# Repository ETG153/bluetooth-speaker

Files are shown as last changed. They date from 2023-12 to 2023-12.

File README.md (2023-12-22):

# Bluetooth-speaker
Wireless bluetooth speaker with high quality sound.

## Features
- Custom made sound card with an ESP32 and a high quality 24bit 192khz dac, Hi-Fi quality
- Completely wireless: battery charging and BMS included
- Amplifiers and crossover custom made for this product, design is power efficient
- Can support LDAC bluetooth codec for higher music bitrate (up to 990 kbps)

## Documentation
- Schematics can be found in the hardware folder
- Code is self explanatory, thus no documentation is needed
- PlatformIO: https://platformio.org/
- DAC datasheet: https://statics.cirrus.com/pubs/proDatasheet/CS4344-45-48_F2.pdf
- ESP32 datasheet: https://www.espressif.com/sites/default/files/documentation/esp32-wroom-32e_esp32-wroom-32ue_datasheet_en.pdf
- Bluetooth library used: https://github.com/pschatzmann/ESP32-A2DP

- Oamk documentation in its own folder

## Architecture

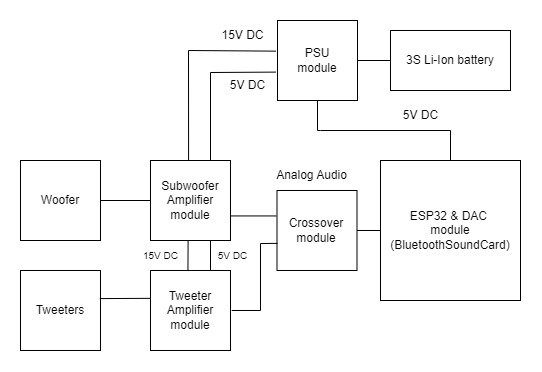
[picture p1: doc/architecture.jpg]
architecture


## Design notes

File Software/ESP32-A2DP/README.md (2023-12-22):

# A Simple Arduino Bluetooth Music Receiver and Sender for the ESP32

The ESP32 is a microcontroller that provides an API for Bluetooth A2DP which can be used to receive sound data e.g. from your Mobile Phone and makes it available via a callback method. The output is a PCM data stream, decoded from SBC format. The documentation can be found [here](https://docs.espressif.com/projects/esp-idf/en/latest/esp32/api-reference/peripherals/i2s.html). 

esp32

I2S is an electrical serial bus interface standard used for connecting digital audio devices together. It is used to communicate PCM audio data between integrated circuits in an electronic device.

So we can just feed the input from Bluetooth to the I2S output: An example for this from Espressif can be found on [Github](https://github.com/espressif/esp-idf/tree/master/examples/bluetooth/bluedroid/classic_bt/a2dp_sink).

Unfortunately this example did not make me happy so I decided to convert it into a simple __Arduino Library__ that is very easy to use from an Arduino Software IDE.

## Supported Bluetooth Protocols

As the name of this libariy implies, it supports the A2DP [Bluetooth protocol](https://en.wikipedia.org/wiki/List_of_Bluetooth_profiles) which only provides audio streaming! 

It also supports Audio/Video Remote Control Profile (AVRCP) together with A2DP.

The Hands-Free Profile (HFP), Headset Profile (HSP) and stand alone AVRCP without A2DP are __not__ supported!

## A2DP Sink (Music Receiver)

This can be used e.g. to build your own Bluetooth Speaker.

### A Simple I2S Example (A2DS Sink) using default Pins
Here is the simplest example which just uses the proper default settings:

```
#include "BluetoothA2DPSink.h"

BluetoothA2DPSink a2dp_sink;

void setup() {
    a2dp_sink.start("MyMusic");
}

void loop() {
}
```
This creates a new Bluetooth device with the name “MyMusic” and the output will be sent to the following default I2S pins which need to be conected to an external DAC:
- bck_io_num = 26
- ws_io_num = 25
- data_out_num = 22

### Defining Pins

You can define your own pins easily by calling the ```set_pin_config``` method in the setup before the ```start```.

```
#include "BluetoothA2DPSink.h"

BluetoothA2DPSink a2dp_sink;

void setup() {
    i2s_pin_config_t my_pin_config = {
        .mck_io_num = I2S_PIN_NO_CHANGE,
        .bck_io_num = 26,
        .ws_io_num = 25,
        .data_out_num = 22,
        .data_in_num = I2S_PIN_NO_CHANGE
    };
    a2dp_sink.set_pin_config(my_pin_config);
    a2dp_sink.start("MyMusic");
}

void loop() {
}
```

### Using your specific i2s_config

In some cases you might want to use your specific i2s_config settings. E.g. to request a different bits_per_sample (e.g. 32) or to use the use_apll or to optimize the dma buffer...

```
#include "BluetoothA2DPSink.h"

BluetoothA2DPSink a2dp_sink;

void setup() {

    static i2s_config_t i2s_config = {
      .mode = (i2s_mode_t) (I2S_MODE_MASTER | I2S_MODE_TX),
      .sample_rate = 44100, // updated automatically by A2DP
      .bits_per_sample = (i2s_bits_per_sample_t)32,
      .channel_format = I2S_CHANNEL_FMT_RIGHT_LEFT,
      .communication_format = (i2s_comm_format_t) (I2S_COMM_FORMAT_STAND_I2S),
      .intr_alloc_flags = 0, // default interrupt priority
      .dma_buf_count = 8,
      .dma_buf_len = 64,
      .use_apll = true,
      .tx_desc_auto_clear = true // avoiding noise in case of data unavailability
  };
  a2dp_sink.set_i2s_config(i2s_config);
  a2dp_sink.start("MyMusic");
}

void loop() {
}

```

### Output to the Internal DAC
You can also send the output directly to the internal DAC of the ESP32 by providing the corresponding i2s_config:

```
#include "BluetoothA2DPSink.h"

BluetoothA2DPSink a2dp_sink;

void setup() {
    static const i2s_config_t i2s_config = {
        .mode = (i2s_mode_t) (I2S_MODE_MASTER | I2S_MODE_TX | I2S_MODE_DAC_BUILT_IN),
        .sample_rate = 44100, // corrected by info from bluetooth
        .bits_per_sample = (i2s_bits_per_sample_t) 16, /* the DAC module will only take the 8bits from MSB */
        .channel_format = I2S_CHANNEL_FMT_RIGHT_LEFT,
        .communication_format = (i2s_comm_format_t)I2S_COMM_FORMAT_STAND_MSB,
        .intr_alloc_flags = 0, // default interrupt priority
        .dma_buf_count = 8,
        .dma_buf_len = 64,
        .use_apll = false
    };

    a2dp_sink.set_i2s_config(i2s_config);
    a2dp_sink.start("MyMusic");

}

void loop() {
}
```

The output goes now to the DAC pins GPIO25 (Channel 1) and GPIO26 (Channel 2).

### Accessing the Sink Data Stream with Callbacks

You can be notified when a packet is received. The API is using PCM data normally formatted as 44.1kHz sampling rate, two-channel 16-bit sample data. 

```
// In the setup function:
a2dp_sink.set_on_data_received(data_received_callback);

// Then somewhere in your sketch:
void data_received_callback() {
  Serial.println("Data packet received");
}
```

Or you can access the packet:

```
// In the setup function:
a2dp_sink.set_stream_reader(read_data_stream);

// Then somewhere in your sketch:
void read_data_stream(const uint8_t *data, uint32_t length)
{
  int16_t *samples = (int16_t*) data;
  uint32_t sample_count = length/2;
  // Do something with the data packet
}
```
In the ```a2dp_sink.set_stream_reader()``` method you can provide an optional parameter that defines if you want the output to I2S to be active or deactive - So you can use this method to e.g. to switch off I2S just by calling ```a2dp_sink.set_stream_reader(read_data_stream, false)```

### Support for Metadata

You can register a method which will be called when the system receives any AVRC metadata. Here is an example
```
void avrc_metadata_callback(uint8_t data1, const uint8_t *data2) {
  Serial.printf("AVRC metadata rsp: attribute id 0x%x, %s\n", data1, data2);
}
a2dp_sink.set_avrc_metadata_callback(avrc_metadata_callback);
a2dp_sink.start("BT");
```
By default you should get the most important information, however you can adjust this by calling the ```set_avrc_metadata_attribute_mask``` method e.g if you just need the title and playing time you can call:
```
set_avrc_metadata_attribute_mask(ESP_AVRC_MD_ATTR_TITLE | ESP_AVRC_MD_ATTR_PLAYING_TIME);
```
before you start the A2DP sink.

### Support for AVRC Commands

I have added the following AVRC commmands, that you can use to 'control' your A2DP Source:

- play();
- pause();
- stop();
- next();
- previous();
- fast_forward();
- rewind();

## A2DP Source (Music Sender)

This can be used to feed e.g. your Bluetooth Speaker with your audio data.

### Sending Data from a A2DS Data Source with a Callback

We can also generate sound and send it e.g. to a Bluetooth Speaker.  

The supported audio codec in ESP32 A2DP is SBC: The API is using PCM data normally formatted as 44.1kHz sampling rate, two-channel 16-bit sample data. 

When you start the BluetoothA2DPSource, you need to pass the Bluetooth name that you want to connect to and a 'call back
function' that generates the sound data:

```
#include "BluetoothA2DPSource.h"

BluetoothA2DPSource a2dp_source;

// callback 
int32_t get_sound_data(Frame *data, int32_t frameCount) {
    // generate your sound data 
    // return the effective length (in frames) of the generated sound  (which usually is identical with the requested len)
    // 1 frame is 2 channels * 2 bytes = 4 bytes
    return frameCount;
}

void setup() {
  a2dp_source.start("MyMusic", get_sound_data);  
}

void loop() {
}

```

In the examples you can find an implentation that generates sound with the help of the sin() function.
You can also inticate multiple alternative Bluetooth names. The system just connects to the first one
which is available:

```
void setup() {
  static std::vector<char*> bt_names = {"MyMusic","RadioPlayer","MusicPlayer"};
  a2dp_source.start(bt_names, get_sound_data); 
} 

```

### Sending Data from a A2DS Data Source with Recorded Data

You can also provide the data directly as simple array of uint8_t:

```
#include "BluetoothA2DPSource.h"

extern const uint8_t StarWars10_raw[];
extern const unsigned int StarWars10_raw_len;

BluetoothA2DPSource a2dp_source;
SoundData *music = new OneChannelSoundData((int16_t*)StarWars30_raw, StarWars30_raw_len/2);

void setup() {
  a2dp_source.start("RadioPlayer");  
  a2dp_source.write_data(music);
}

void loop() {
}

```

The array can be prepared e.g. in the following way:

  - Open any sound file in Audacity. 
    - Select Tracks -> Resample and select 44100
    - Export -> Export Audio -> Header Raw ; Signed 16 bit PCM
  - Convert to c file e.g. with "xxd -i file_example_WAV_1MG.raw file_example_WAV_1MG.c"
    - add the const qualifier to the generated array definition. E.g const unsigned char file_example_WAV_1MG_raw[] = {

You might want to compile with the Partition Scheme: Huge App!

In the example above we provide the data with one channel. This has the advantage that it uses much less space then 
a 2 channel recording, which you could use in the following way: 

```
SoundData *data = new TwoChannelSoundData((Frame*)StarWars10_raw,StarWars10_raw_len/4);

```

In the constructor you can pass additional parameters:

```
TwoChannelSoundData(Frame *data, int32_t frameCount, bool loop=false);
OneChannelSoundData(int16_t *data, int32_t frameCount, bool loop=false, ChannelInfo channelInfo=Both);
OneChannel8BitSoundData(int8_t *data, int32_t frameCount, bool loop=false, ChannelInfo channelInfo=Both);

```
## Logging

This library uses the ESP32 logger that you can activate in Arduino in - Tools - Core Debug Log.

## Architecture / Dependencies 

The current code is purely dependent on the ESP-IDF (which is also provided by the Arduino ESP32 core). There are no other dependencies and this includes the Arduino API! 

Therefore we support:

- Arduino
- [PlatformIO](https://github.com/pschatzmann/ESP32-A2DP/wiki/PlatformIO)
- [Espressif IDF](https://github.com/pschatzmann/ESP32-A2DP/wiki/Espressif-IDF-as-a-Component)

This restriction limits however the provided examples. 

Before you clone the project, please read the following information which can be found in the [Wiki](https://github.com/pschatzmann/ESP32-A2DP/wiki/Design-Overview).

## Digital Sound Processing

You can use this library stand alone, but it is part of my [audio-tools](https://github.com/pschatzmann/arduino-audio-tools) project. So you can easily enhance this functionality with sound effects, use filters, use alternative audio sinks or audio sources, do FFT etc. Here is a [simple example](https://github.com/pschatzmann/arduino-audio-tools/blob/main/examples/examples-basic-api/basic-a2dp-fft/basic-a2dp-fft.ino) how you can analyse the audio data with FFT.

## Documentation

- The [class documentation can be found here](https://pschatzmann.github.io/ESP32-A2DP/html/group__a2dp.html)
- You can also find further information in the [Wiki](https://github.com/pschatzmann/ESP32-A2DP/wiki)

## Support

I spent a lot of time to provide a comprehensive and complete documentation.
So please read the documentation first and check the issues and discussions before posting any new ones on Github.

Open issues only for bugs and if it is not a bug, use a discussion: Provide enough information about 
- the selected scenario/sketch 
- what exactly you are trying to do
- your hardware
- your software versions
  - ESP32 version from the Board Manager
  - version of the ESP32-A2DP library

to enable others to understand and reproduce your issue.

Finally above all __don't__ send me any e-mails or post questions on my personal website! 

## Show and Tell

Get some inspiration [from projects that were using this library](https://github.com/pschatzmann/ESP32-A2DP/discussions/categories/show-and-tell) and share your projects with the community.

## Installation

For Arduino you can download the library as zip and call include Library -> zip library. Or you can git clone this project into the Arduino libraries folder e.g. with
```
cd  ~/Documents/Arduino/libraries
git clone https://github.com/pschatzmann/ESP32-A2DP.git
```

For other frameworks [see the Wiki](https://github.com/pschatzmann/ESP32-A2DP/wiki)

## Change History

The [Change History can be found in the Wiki](https://github.com/pschatzmann/ESP32-A2DP/wiki/Change-History)

## Sponsor Me

This software is totally free, but you can make me happy by rewarding me with a treat

- [Buy me a coffee](https://www.buymeacoffee.com/philschatzh)
- [Paypal me](https://paypal.me/pschatzmann?country.x=CH&locale.x=en_US)

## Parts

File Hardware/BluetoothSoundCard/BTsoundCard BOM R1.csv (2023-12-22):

Qty | Value | Device | Package | Parts | Description
5 |  | 10-XX | B3F-10XX | S1, S2, S3, S4, S5 | OMRON SWITCH
1 |  | LEDCHIP-LED0603 | CHIP-LED0603 | LED2 | LED
4 |  | MMBT3904 | SOT23 | T1, T2, T3, T4 | NPN Transistor
1 |  | MMFTP3401 | SOT-23 | T5 | MOS FET
1 |  | PINHD-1X2 | 1X02 | JP1 | PIN HEADER
2 |  | R-EU_R0805 | R0805 | FE, FE1 | FERRITE BEAD
1 |  | W237-103 | W237-103 | X1 | WAGO SCREW CLAMP
2 |  | W237-4 | W237-4 | X2, X4 | WAGO SCREW CLAMP
14 | 100n | C-EUC0603 | C0603 | C2, C5, C9, C13, C16, C17, C18, C19, C21, C22, C23, C24, C25, C26 | CAPACITOR, European symbol
7 | 10k | R-EU_R0603 | R0603 | R1, R2, R3, R4, R5, R7, R15 | RESISTOR, European symbol
1 | 10k | R-EU_R0805 | R0805 | R10 | RESISTOR, European symbol
2 | 10n | C-EUC0603 | C0603 | C6, C11 | CAPACITOR, European symbol
3 | 10u | C-EUC0805 | C0805 | C7, C12, C14 | CAPACITOR, European symbol
1 | 1PS76SB10 | 1PS76SB10 | SOD323(F) | D1 | TVS DIODE
7 | 1k | R-EU_R0603 | R0603 | R8, R13, R16, R17, R18, R19, R20 | RESISTOR, European symbol
1 | 1k | R-EU_R1206 | R1206 | R9 | RESISTOR, European symbol
4 | 1u | C-EUC0603 | C0603 | C3, C4, C10, C20 | CAPACITOR, European symbol
1 | 3X2 | 3X2 | 2X3 | U$3
1 | 3k4 | R-EU_R0603 | R0603 | R11 | RESISTOR, European symbol
1 | 4.7u | EEEFK1H4R7RCAP_EEFK_B_PAN-M | CAP_EEFK_B_PAN-M | C1
1 | 5.1V | DIODE-MINIMELF | MINIMELF | D2 | ZENER DIODE
2 | 82r | R-EU_R1206 | R1206 | R12, R14 | RESISTOR, European symbol
1 | AZ1117H-3.3TRE1SOT-223_DIO-L | AZ1117H-3.3TRE1SOT-223_DIO-L | SOT-223_DIO-L | LDO
1 | CS4344-CZZ | CS4344-CZZ | CIR-TSSOP-10 | U2
1 | ESP32-WROOM-32UE_(16MB) | ESP32-WROOM-32UE_(16MB) | IC38_ESP32-WROOM-32UE_(16MB)_E | U1
1 | JST-XH-04-PIN-LONG-PAD | JST-XH-04-PIN-LONG-PAD | JST-XH-04-PACKAGE-LONG-PAD | UART | JST XH Connector 2 Pin
1 | LD3985M30R | LD3985M30R | SOT23-5L_STM | CR1
1 | MCP602SN | MCP602SN | SO08 | IC1 | Single Op Amp 2.7V to 6.0V Single Supply CMOS
4 | MOUNT-PAD-ROUND3.2 | MOUNT-PAD-ROUND3.2 | 3,2-PAD | H1, H2, H3, H4 | MOUNTING PAD, round
1 | TPPAD1-13 | TPPAD1-13 | P1-13 | TP6 | Test pad
1 | TPSC336K010R0375 | TPSC336K010R0375 | TPSC336K010R0375_AVX | C8 | 33uF low ESR tantalum capacitor

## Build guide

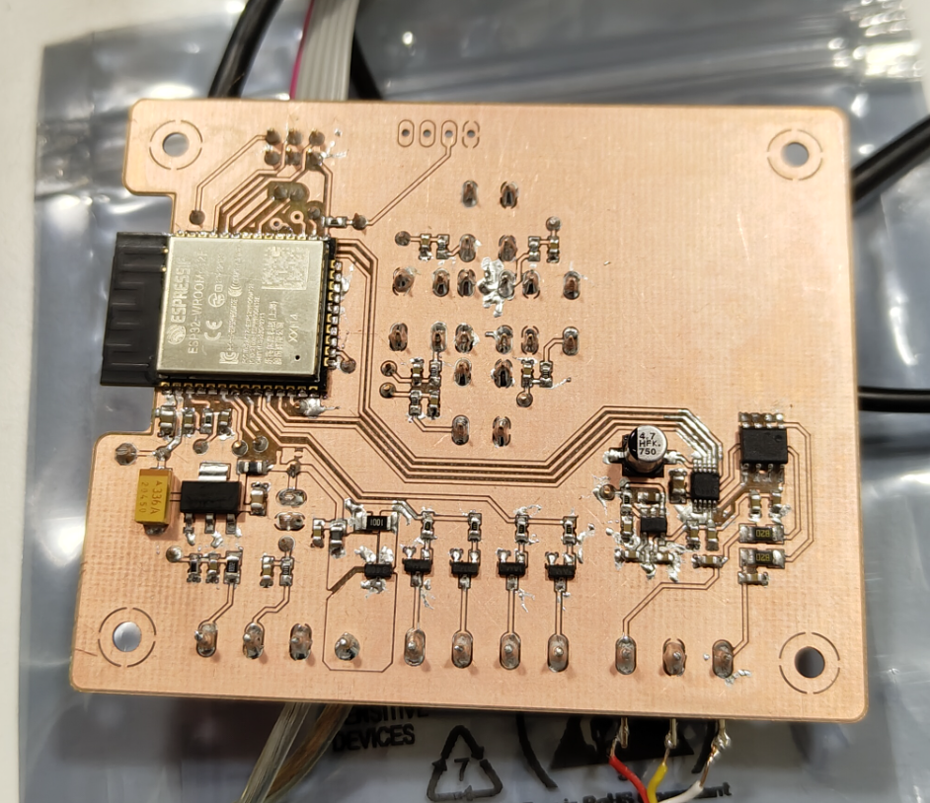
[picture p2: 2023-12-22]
Hardware/BluetoothSoundCard/Proto/assembled-prototype.png

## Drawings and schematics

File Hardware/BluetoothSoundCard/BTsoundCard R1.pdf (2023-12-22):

GND | GND ¹⁰k | 10k 1k GND
10u Power | DAC

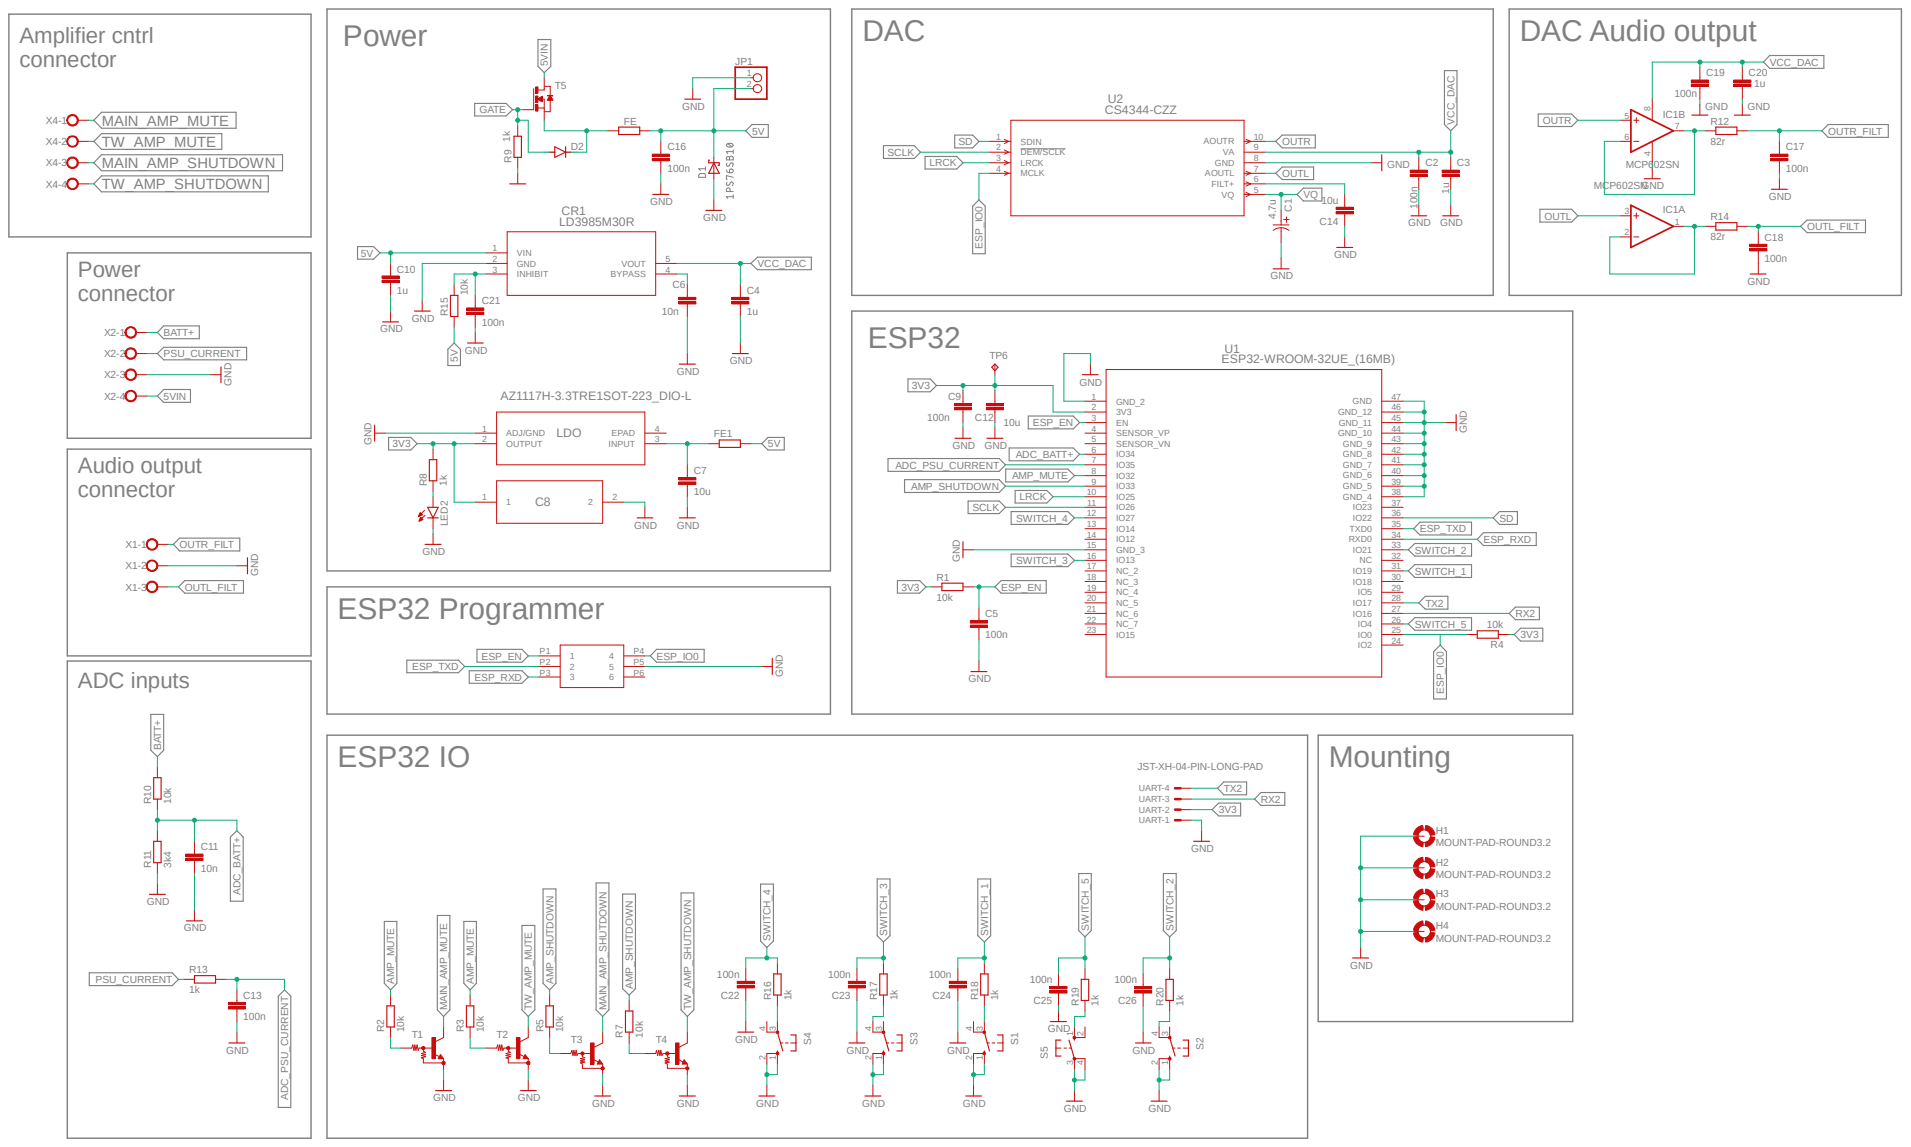
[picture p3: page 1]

IO14 13 IO12 14 | ESP_TXD

NC_7 22 | | 10k
IO15 23 | 3V3

ESP_TXD P2 P3 ESP_RXD | P5 P6

ESP_EN | 1 4 2 5 3 6

JST-XH-04-PIN-LONG-PAD

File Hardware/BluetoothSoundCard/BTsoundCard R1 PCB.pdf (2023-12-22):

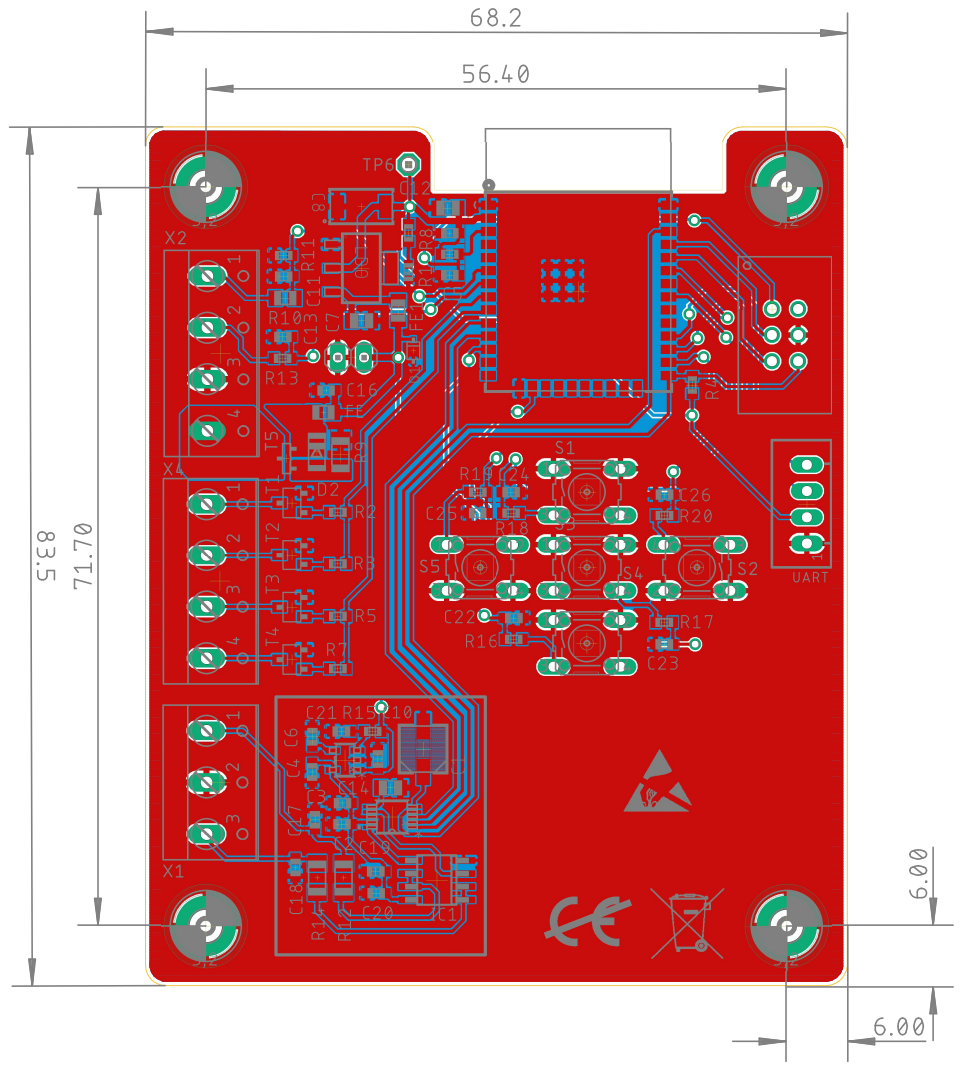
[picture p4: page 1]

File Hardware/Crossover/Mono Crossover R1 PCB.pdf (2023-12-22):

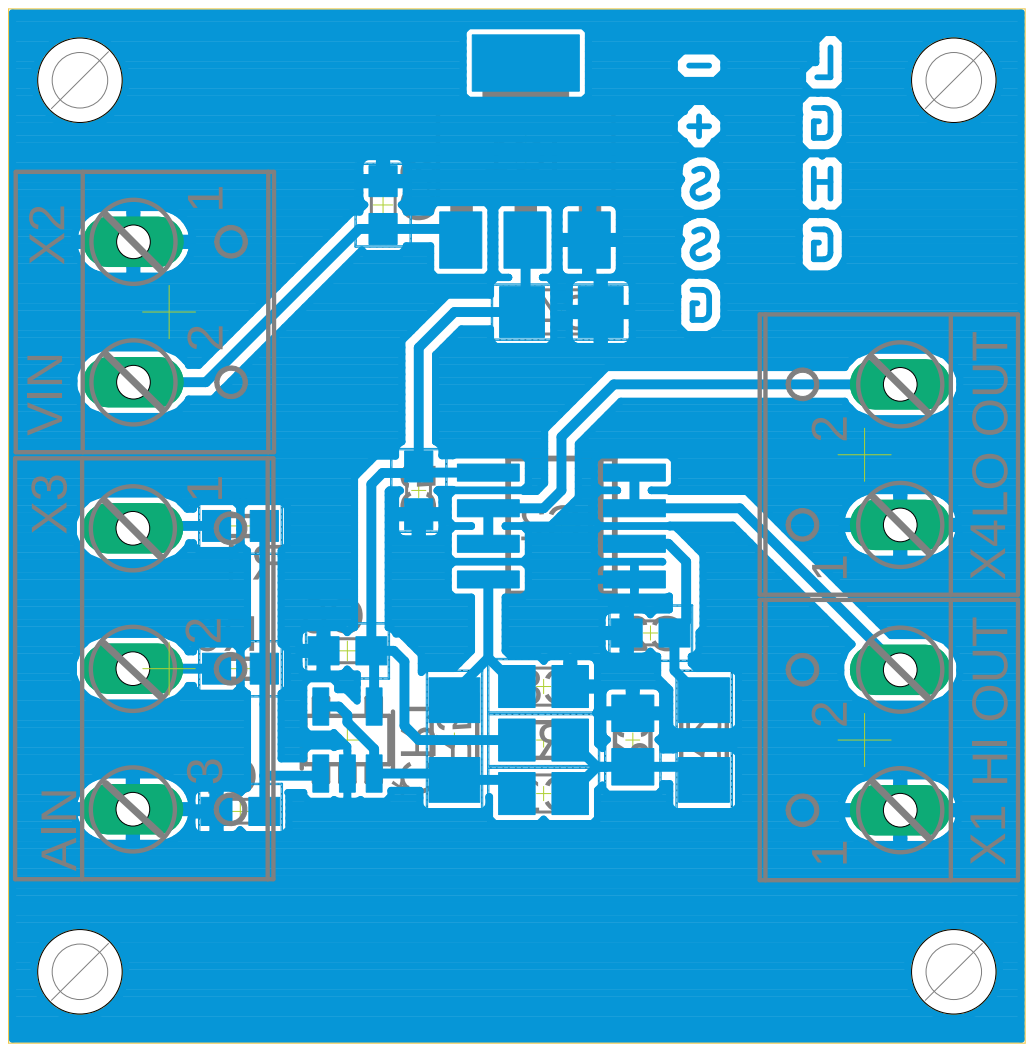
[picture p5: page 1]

CR1 1 C 2 C 8 C C5 C3 4 C 2 CI 1 CI R3 R2R51 R 4 R 6 R 6 C 7 C * 1 2 1 2 1 2 1 2 3 X2 X1 X X4 3 VIN HI OUT LO OUT AIN

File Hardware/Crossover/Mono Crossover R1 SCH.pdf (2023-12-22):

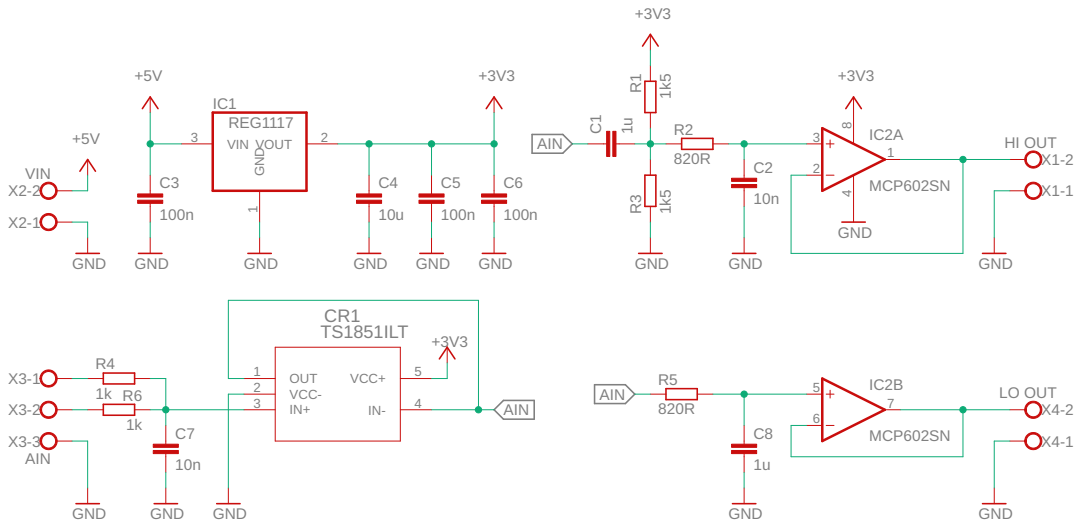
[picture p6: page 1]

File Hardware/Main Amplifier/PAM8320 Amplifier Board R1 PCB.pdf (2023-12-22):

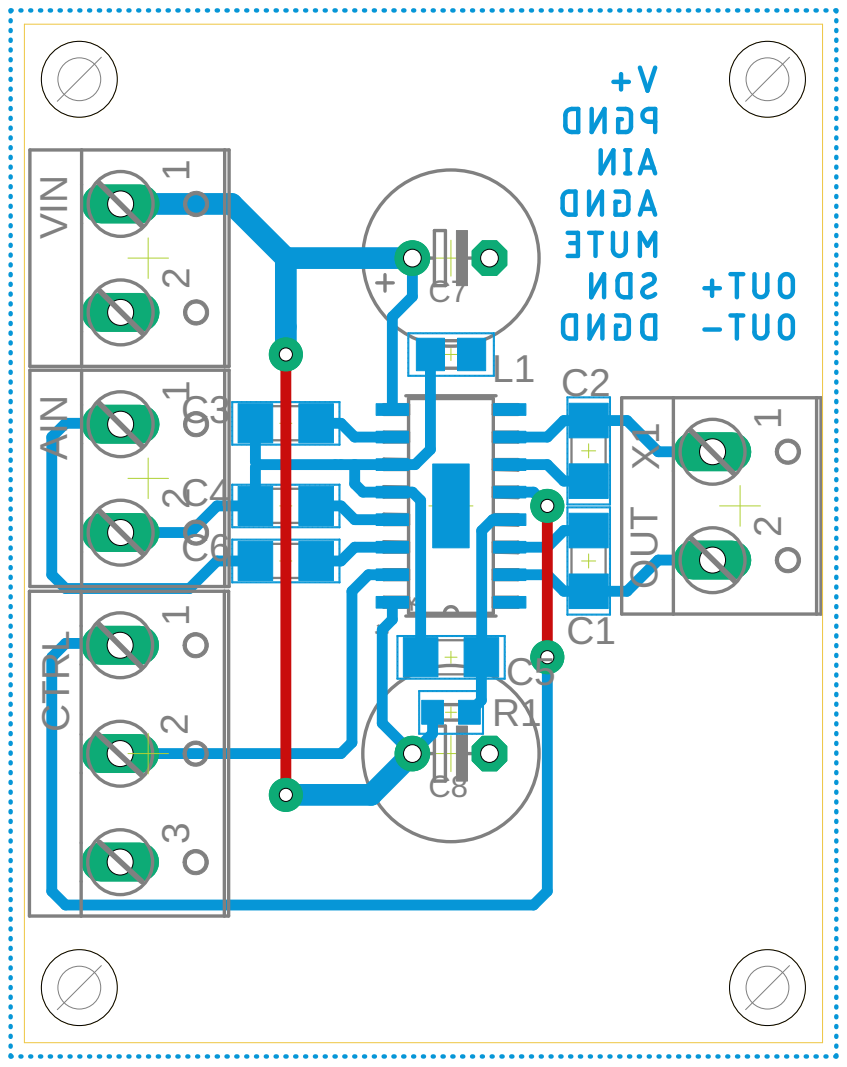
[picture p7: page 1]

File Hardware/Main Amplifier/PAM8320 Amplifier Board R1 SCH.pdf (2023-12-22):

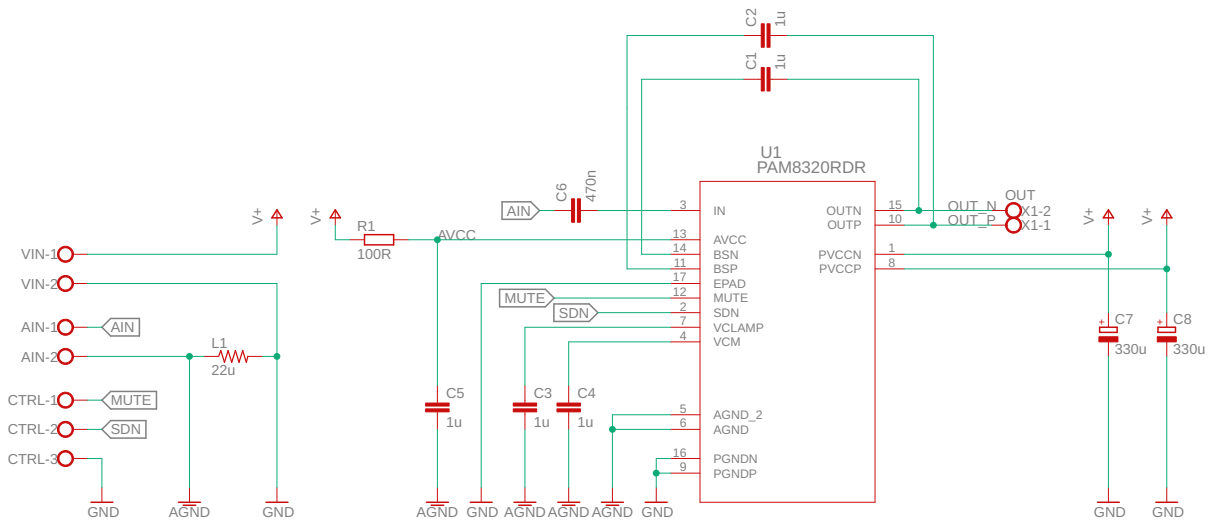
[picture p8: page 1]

13
14

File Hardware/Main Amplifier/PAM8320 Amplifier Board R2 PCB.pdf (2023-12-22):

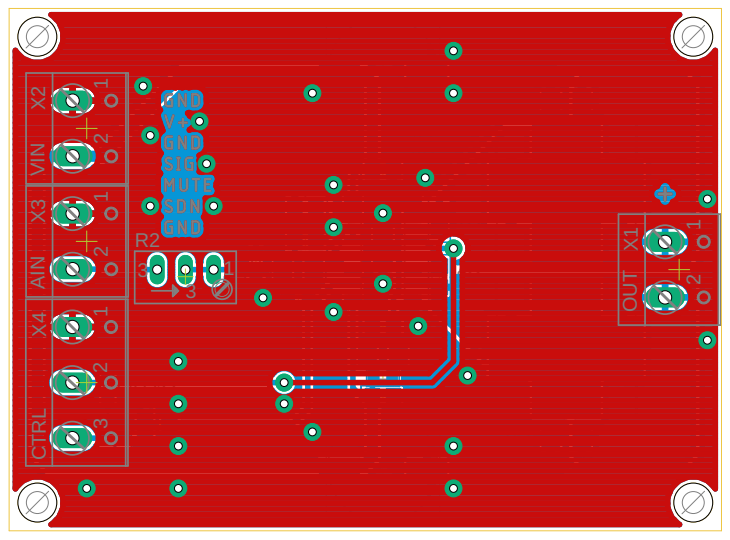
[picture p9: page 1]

2 C1 C 21 C 31 C 11 C 5 C 1 R 8 C9 C 6 C 7 C 01 C 3 C4 C 6 R1 Q 7 R 4 R 5 R * * 1 2 1 2 1 23 1 2 3 3 1 X3 X4 X2 X1R2 AIN CTRL VIN OUT

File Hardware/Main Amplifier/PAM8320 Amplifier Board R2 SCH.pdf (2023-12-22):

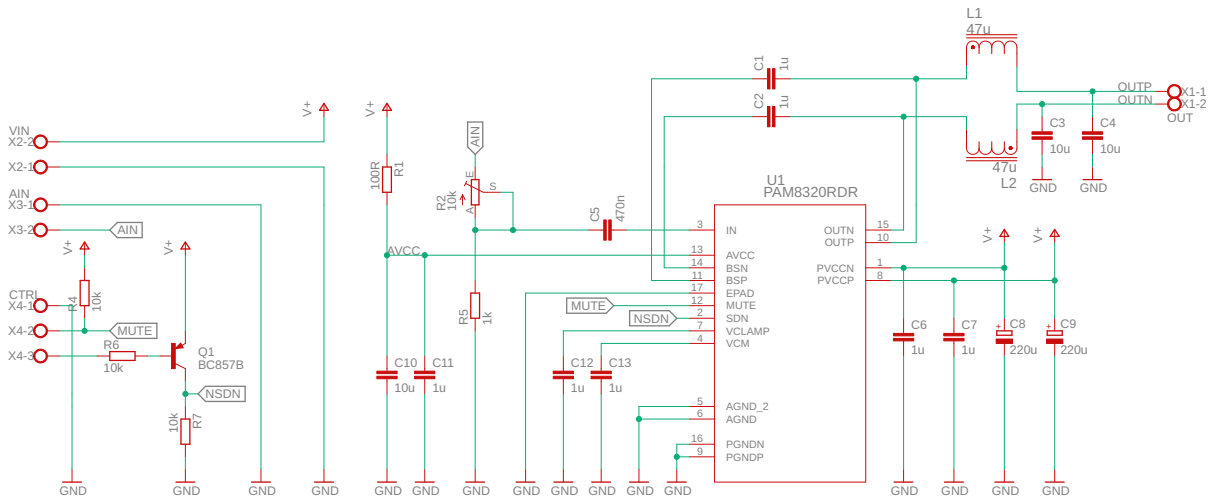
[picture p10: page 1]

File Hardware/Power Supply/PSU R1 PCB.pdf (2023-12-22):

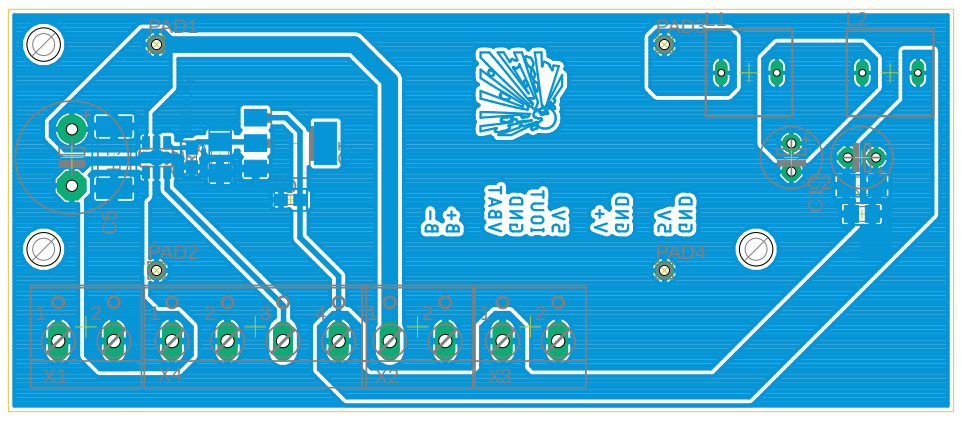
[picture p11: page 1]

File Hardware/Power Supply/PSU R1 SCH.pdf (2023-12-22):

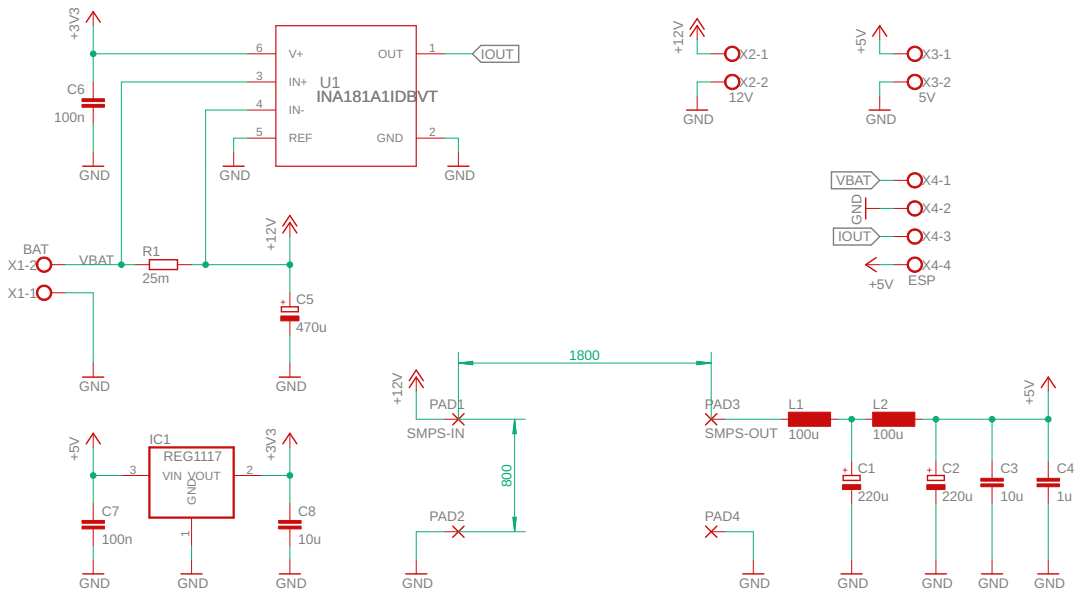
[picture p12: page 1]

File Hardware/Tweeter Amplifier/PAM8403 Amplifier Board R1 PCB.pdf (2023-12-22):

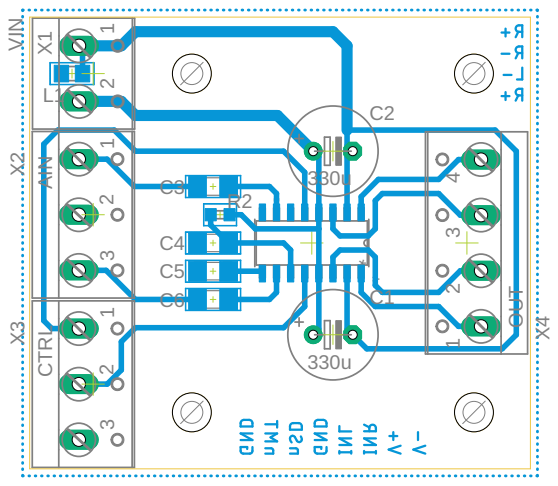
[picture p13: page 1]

* * 1 2 1 2 3 1 2 3 1 2 3 4 C5 C4 C6 X3 L1 R2 X1 C1 C2 X2 C3 X4 CTRL VIN 330u A330u IN OUT

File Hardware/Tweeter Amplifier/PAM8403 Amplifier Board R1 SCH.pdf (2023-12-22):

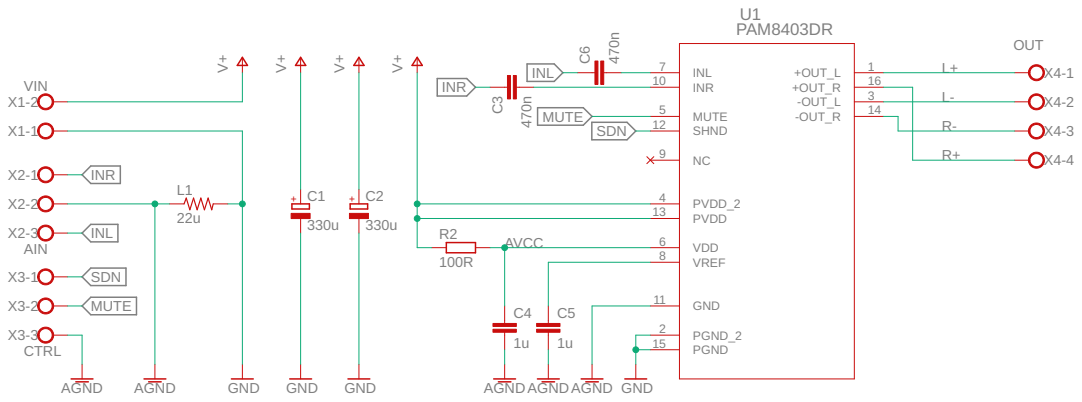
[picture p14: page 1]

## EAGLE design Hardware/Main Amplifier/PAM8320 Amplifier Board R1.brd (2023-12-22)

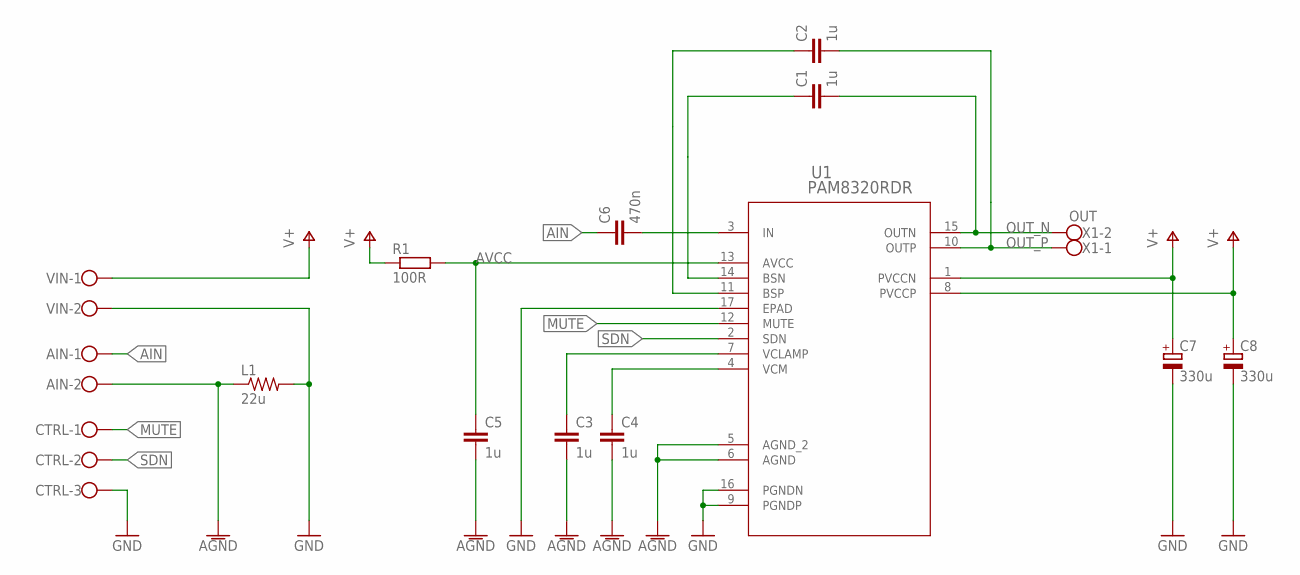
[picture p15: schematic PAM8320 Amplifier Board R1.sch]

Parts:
AIN: W237-102
C1, C2, C3, C4, C5: 1u; C1206
C6: 470n; C1206
C7, C8: 330u; E3,5-8
CTRL: W237-103
L1: 22u; R0805
R1: 100R; R0603
U1: PAM8320RDR; SO-16EP_3P9X9P9_DIO
VIN: W237-102
X1: OUT; W237-102

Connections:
AGND: AIN.2, C3.2, C4.2, C5.2, L1.1, U1.5 (AGND_2), U1.6 (AGND)
AIN: AIN.1, C6.1
AVCC: C5.1, R1.2, U1.13 (AVCC)
BSN: C1.1, U1.14 (BSN)
BSP: C2.1, U1.11 (BSP)
GND: C7.-, C8.-, CTRL.3, L1.2, U1.9 (PGNDP), U1.16 (PGNDN), U1.17 (EPAD), VIN.2
MUTE: CTRL.1, U1.12 (MUTE)
unnamed: C3.1, U1.7 (VCLAMP)
unnamed: C4.1, U1.4 (VCM)
unnamed: C6.2, U1.3 (IN)
OUT_N: C1.2, U1.15 (OUTN), X1.2
OUT_P: C2.2, U1.10 (OUTP), X1.1
SDN: CTRL.2, U1.2 (SDN)
V+: C7.+, C8.+, R1.1, U1.1 (PVCCN), U1.8 (PVCCP), VIN.1

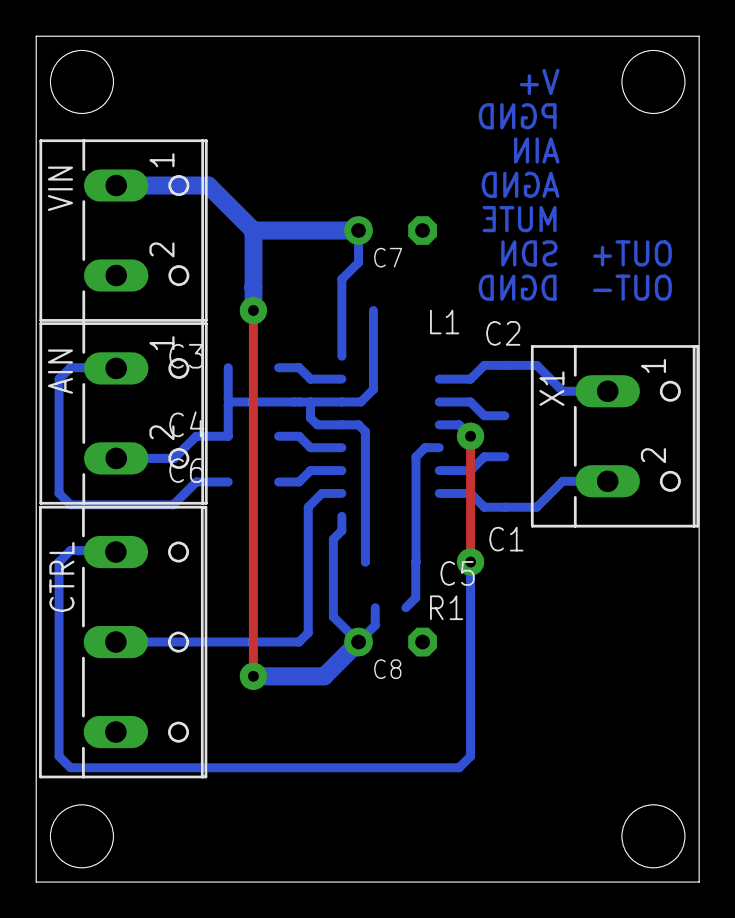
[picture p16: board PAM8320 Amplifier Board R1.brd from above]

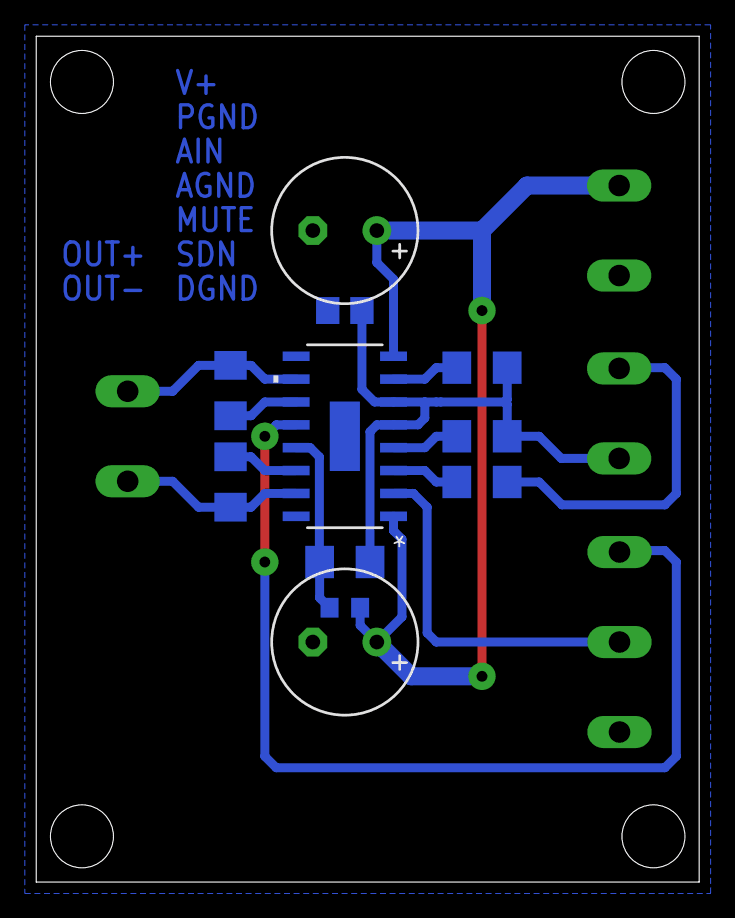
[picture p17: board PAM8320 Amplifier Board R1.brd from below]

Board: 2 copper layers, 36.8 x 47.0 mm, 15 parts (11 on the bottom side), 14 nets.

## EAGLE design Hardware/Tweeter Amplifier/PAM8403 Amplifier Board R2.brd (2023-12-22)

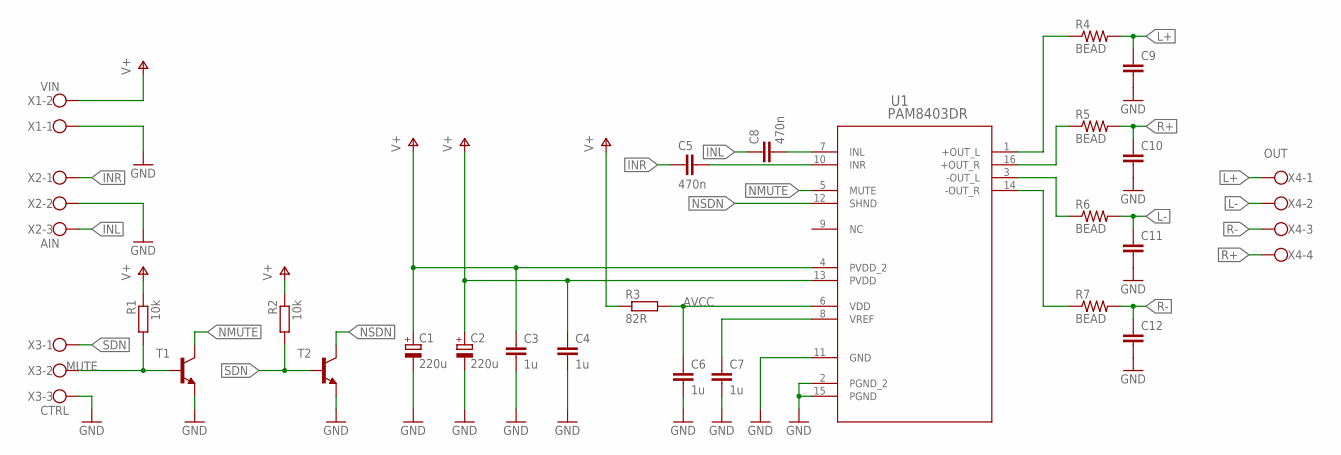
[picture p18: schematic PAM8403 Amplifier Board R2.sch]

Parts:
C1, C2: 220u; UD-10X10_NICHICON
C3, C4, C6, C7: 1u; C0805
C5, C8: 470n; C1206
C9, C10, C11, C12: C-EUC0603; C0603
R1, R2: 10k; R0603
R3: 82R; R1206
R4, R5, R6, R7: BEAD; R0805
T1, T2: MMBT3904LT1-NPN-SOT23-BEC; SOT23-BEC
U1: PAM8403DR; SOIC_8403DR_DIO
X1: VIN; W237-102
X2: AIN; W237-103
X3: CTRL; W237-103
X4: OUT; W237-4

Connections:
AVCC: C6.1, R3.2, U1.6 (VDD)
GND: C1.-, C2.-, C3.2, C4.2, C6.2, C7.2, C9.2, C10.2, C11.2, C12.2, T1.E, T2.E, U1.2 (PGND_2), U1.11 (GND), U1.15 (PGND), X1.1, X2.2, X3.3
INL: C8.1, X2.3
INR: C5.1, X2.1
L: C8.2, U1.7 (INL)
L+: C9.1, R4.2, X4.1
L-: C11.1, R6.2, X4.2
MUTE: R1.2, T1.B, X3.2
unnamed: R5.1, U1.16 (+OUT_R)
unnamed: R6.1, U1.3 (-OUT_L)
unnamed: R4.1, U1.1 (+OUT_L)
unnamed: R7.1, U1.14 (-OUT_R)
NMUTE: T1.C, U1.5 (MUTE)
NSDN: T2.C, U1.12 (SHND)
R: C5.2, U1.10 (INR)
R+: C10.1, R5.2, X4.4
R-: C12.1, R7.2, X4.3
SDN: R2.2, T2.B, X3.1
V+: C1.+, C2.+, C3.1, C4.1, R1.1, R2.1, R3.1, U1.4 (PVDD_2), U1.13 (PVDD), X1.2
VREF: C7.1, U1.8 (VREF)

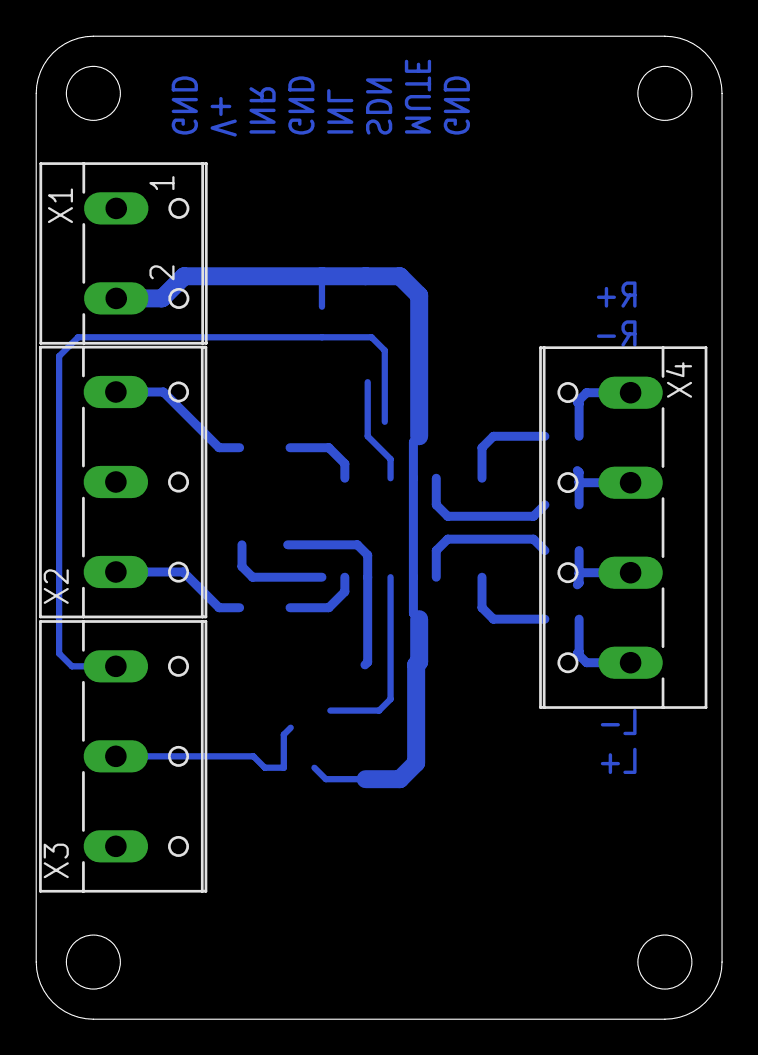
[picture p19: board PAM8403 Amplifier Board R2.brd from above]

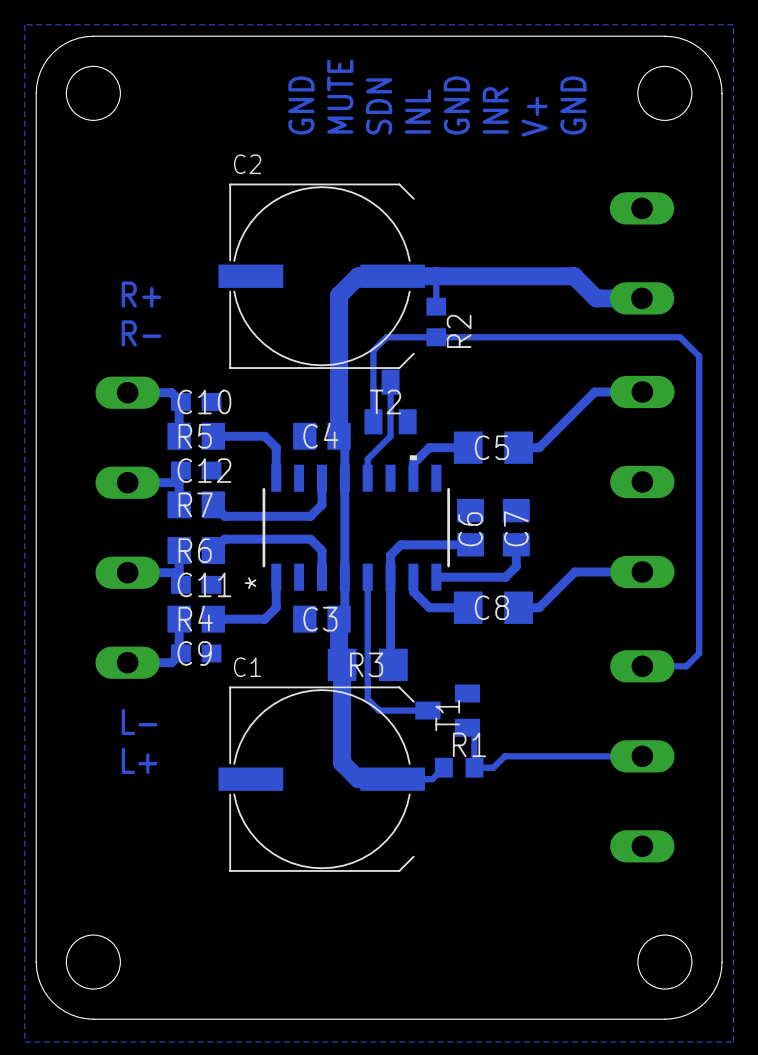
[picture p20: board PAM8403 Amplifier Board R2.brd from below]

Board: 2 copper layers, 38.1 x 54.6 mm, 26 parts (22 on the bottom side), 20 nets.

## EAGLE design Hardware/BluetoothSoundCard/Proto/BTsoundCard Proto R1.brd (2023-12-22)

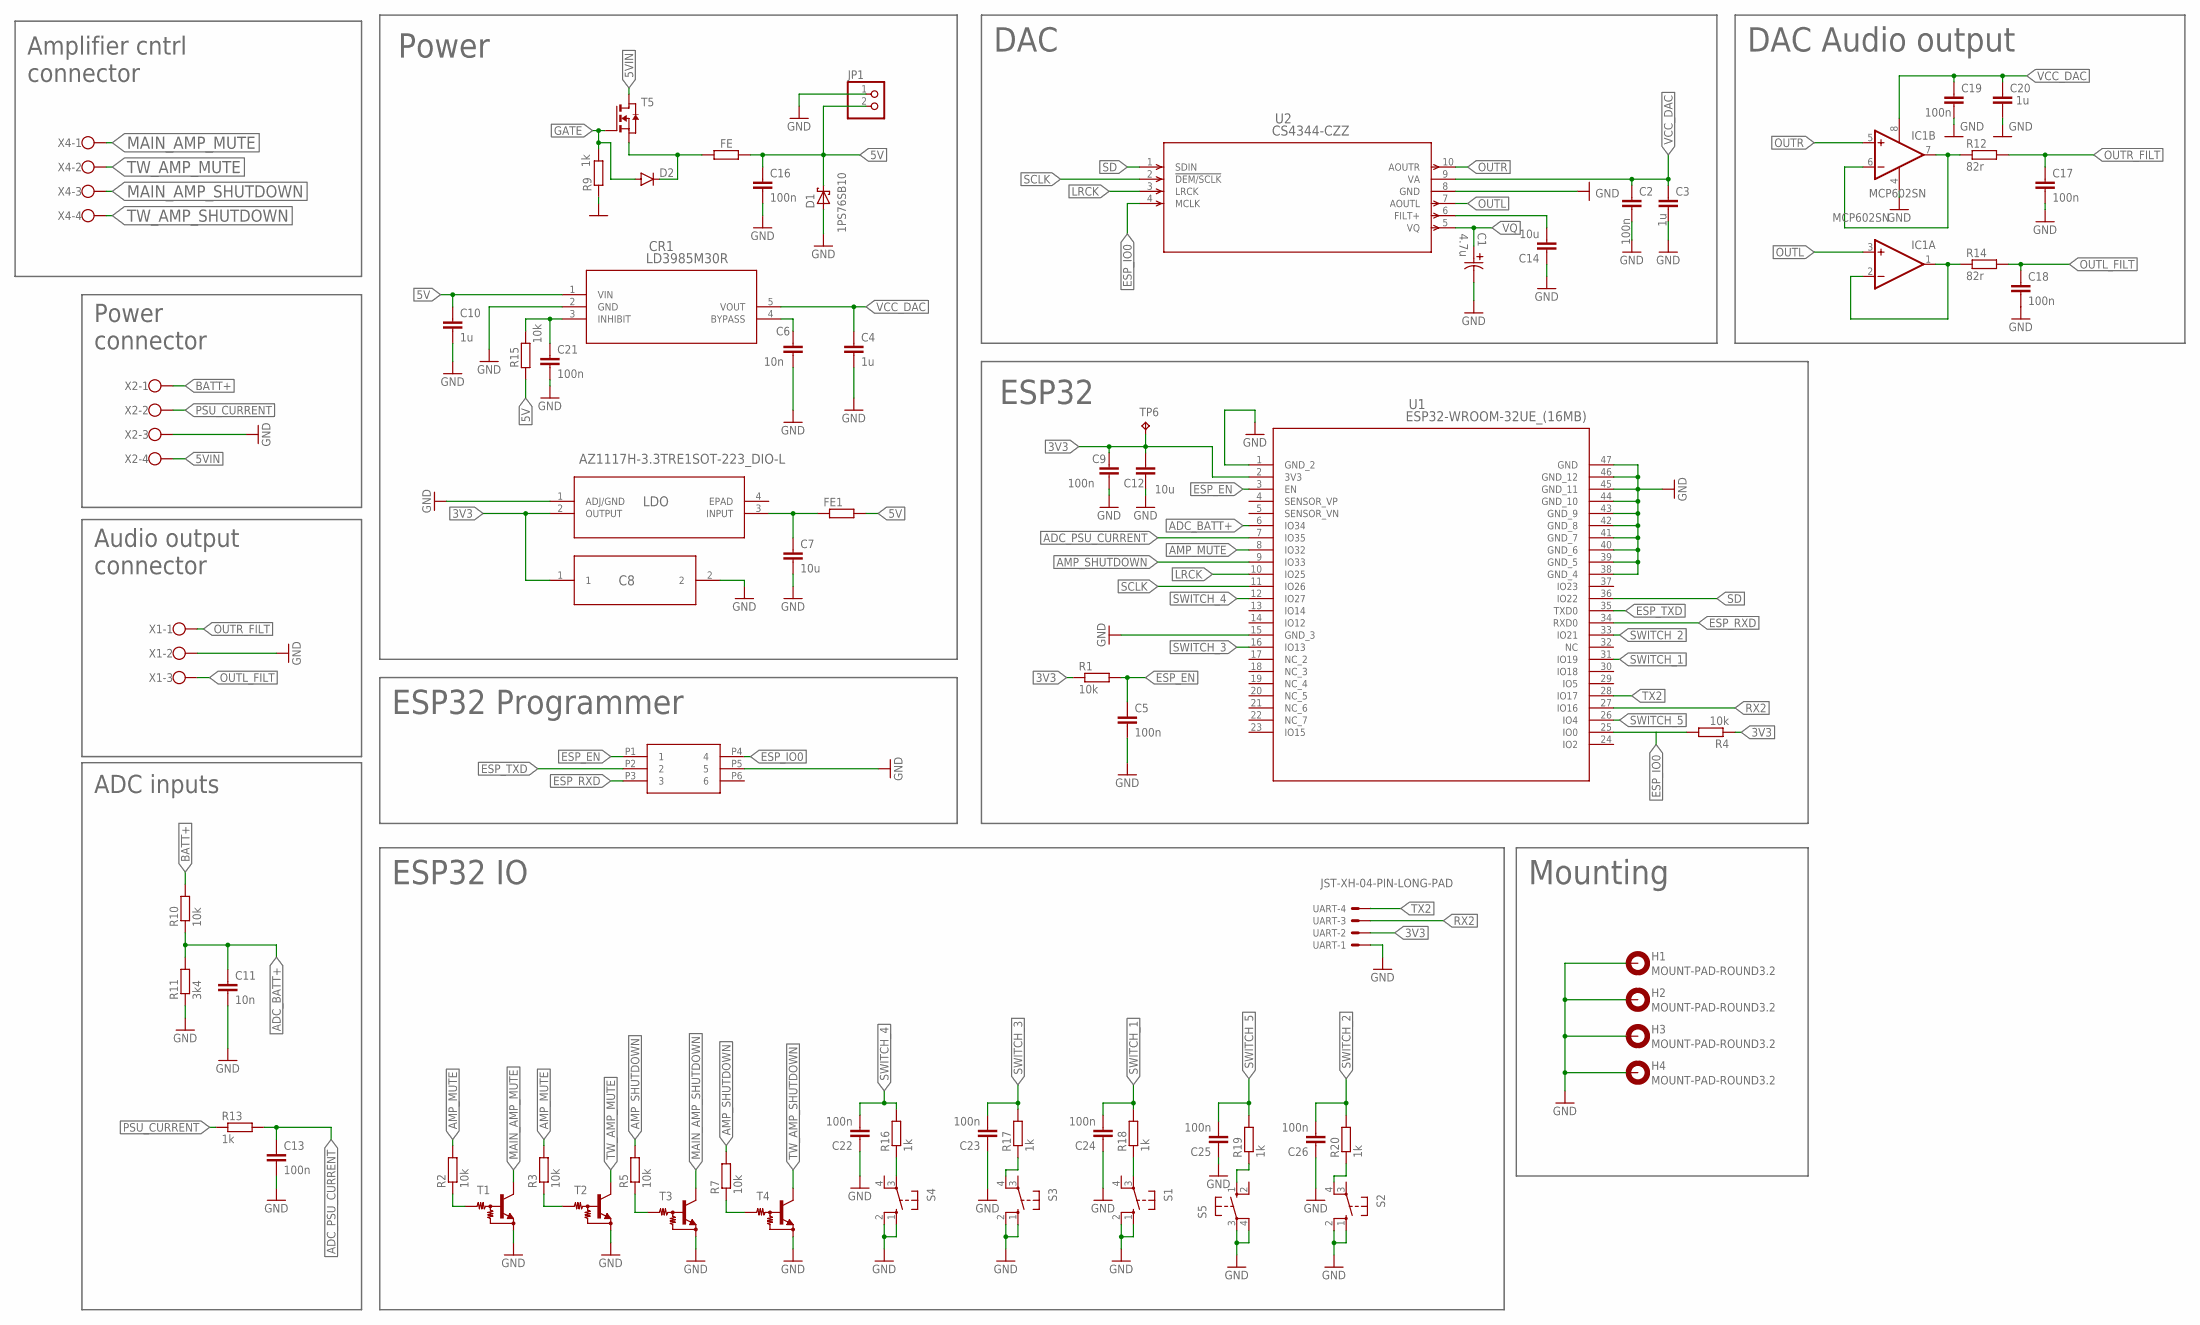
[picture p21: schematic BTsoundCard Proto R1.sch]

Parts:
C1: 4.7u; CAP_EEFK_B_PAN-M
C2, C5, C9, C13, C16, C17, C18, C19, C21, C22, C23, C24, C25, C26: 100n; C0603
C3, C4, C10, C20: 1u; C0603
C6, C11: 10n; C0603
C7, C12, C14: 10u; C0805
C8: TPSC336K010R0375; TPSC336K010R0375_AVX
CR1: LD3985M30R; SOT23-5L_STM
D1: 1PS76SB10; SOD323(F)
D2: 5.1V; MINIMELF
FE, FE1: R-EU_R0805; R0805
H1, H2, H3, H4: MOUNT-PAD-ROUND3.2; 3,2-PAD
IC1: MCP602SN; SO08
JP1: PINHD-1X2; 1X02
LDO: AZ1117H-3.3TRE1SOT-223_DIO-L; SOT-223_DIO-L
R1, R2, R3, R4, R5, R7, R15: 10k; R0603
R9: 1k; R1206
R10: 10k; R0805
R11: 3k4; R0603
R12, R14: 82r; R1206
R13, R16, R17, R18, R19, R20: 1k; R0603
S1, S2, S3, S4, S5: 10-XX; B3F-10XX
T1, T2, T3, T4: MUN2212T1-NPN_DRIVER-SC59-BEC; SC59-BEC
T5: NMOSSOT23; SOT-23
TP6: TPPAD1-13; P1-13
U1: ESP32-WROOM-32UE_(16MB); IC38_ESP32-WROOM-32UE_(16MB)_E
U2: CS4344-CZZ; CIR-TSSOP-10
U$3: 3X2; 2X3
UART: JST-XH-04-PIN-LONG-PAD; JST-XH-04-PACKAGE-LONG-PAD
X1: W237-103
X2, X4: W237-4

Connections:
3V3: C8.1, C9.1, C12.2, LDO.2 (OUTPUT), R1.1, R4.1, TP6.TP, U1.2 (3V3), UART.2
5V: C10.1, C16.1, CR1.1 (VIN), D1.1 (K), FE.2, FE1.2, JP1.2, R15.1
5VIN: T5.1 (D), X2.4
ADC_BATT+: C11.1, R10.1, R11.2, U1.6 (IO34)
ADC_PSU_CURRENT: C13.1, R13.2, U1.7 (IO35)
AMP_MUTE: R2.2, R3.2, U1.8 (IO32)
AMP_SHUTDOWN: R5.2, R7.2, U1.9 (IO33)
BATT+: R10.2, X2.1
ESP_EN: C5.1, R1.2, U1.3 (EN), U$3.P1 (1)
ESP_IO0: R4.2, U1.25 (IO0), U2.4 (MCLK), U$3.P4 (4)
ESP_RXD: U1.34 (RXD0), U$3.P3 (3)
ESP_TXD: U1.35 (TXD0), U$3.P2 (2)
GATE: D2.A, R9.2, T5.3 (G)
GND: C1.2, C2.2, C3.2, C4.2, C5.2, C6.2, C7.2, C8.2, C9.2, C10.2, C11.2, C12.1, C13.2, C14.1, C16.2, C17.2, C18.2, C19.2, C20.2, C21.2, C22.1, C23.1, C24.1, C25.1, C26.1, CR1.2 (GND), D1.2 (A), H1.B3,2, H2.B3,2, H3.B3,2, H4.B3,2, IC1.4 (V-), JP1.1, LDO.1 (ADJ/GND), R9.1, R11.1, S1.1 (S), S1.2 (S1), S2.1 (S), S2.2 (S1), S3.1 (S), S3.2 (S1), S4.1 (S), S4.2 (S1), S5.3, S5.4 (P1), T1.E, T2.E, T3.E, T4.E, U1.1 (GND_2), U1.15 (GND_3), U1.38 (GND_4), U1.39 (GND_5), U1.40 (GND_6), U1.41 (GND_7), U1.42 (GND_8), U1.43 (GND_9), U1.44 (GND_10), U1.45 (GND_11), U1.46 (GND_12), U1.47 (GND), U2.8 (GND), U$3.P5 (5), UART.1, X1.2, X2.3
LRCK: U1.10 (IO25), U2.3 (LRCK)
MAIN_AMP_MUTE: T1.C, X4.1
MAIN_AMP_SHUTDOWN: T3.C, X4.3
unnamed: IC1.6 (-IN), IC1.7 (OUT), R12.1
unnamed: R16.1, S4.3
unnamed: C6.1, CR1.4 (BYPASS)
unnamed: R17.1, S3.4 (P1)
unnamed: C14.2, U2.6 (FILT+)
unnamed: C7.1, FE1.1, LDO.3 (INPUT)
unnamed: R2.1, T1.B
unnamed: R3.1, T2.B
unnamed: R5.1, T3.B
unnamed: R7.1, T4.B
unnamed: R18.1, S1.3
unnamed: C21.1, CR1.3 (INHIBIT), R15.2
unnamed: R19.1, S5.1 (S)
unnamed: R20.1, S2.4 (P1)
unnamed: D2.C, FE.1, T5.2 (S)
unnamed: IC1.1 (OUT), IC1.2 (-IN), R14.1
OUTL: IC1.3 (+IN), U2.7 (AOUTL)
OUTL_FILT: C18.1, R14.2, X1.3
OUTR: IC1.5 (+IN), U2.10 (AOUTR)
OUTR_FILT: C17.1, R12.2, X1.1
PSU_CURRENT: R13.1, X2.2
RX2: U1.27 (IO16), UART.3
SCLK: U1.11 (IO26), U2.2 (!DEM/SCLK)
SD: U1.36 (IO22), U2.1 (SDIN)
SWITCH_1: C24.2, R18.2, U1.31 (IO19)
SWITCH_2: C26.2, R20.2, U1.33 (IO21)
SWITCH_3: C23.2, R17.2, U1.16 (IO13)
SWITCH_4: C22.2, R16.2, U1.12 (IO27)
SWITCH_5: C25.2, R19.2, U1.26 (IO4)
TW_AMP_MUTE: T2.C, X4.2
TW_AMP_SHUTDOWN: T4.C, X4.4
TX2: U1.28 (IO17), UART.4
VCC_DAC: C2.1, C3.1, C4.1, C19.1, C20.1, CR1.5 (VOUT), IC1.8 (V+), U2.9 (VA)
VQ: C1.1, U2.5 (VQ)

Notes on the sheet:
Power
DAC
ESP32
ESP32 Programmer
ESP32 IO
Mounting
Amplifier cntrl connector
Power connector
Audio output connector
ADC inputs
DAC Audio output

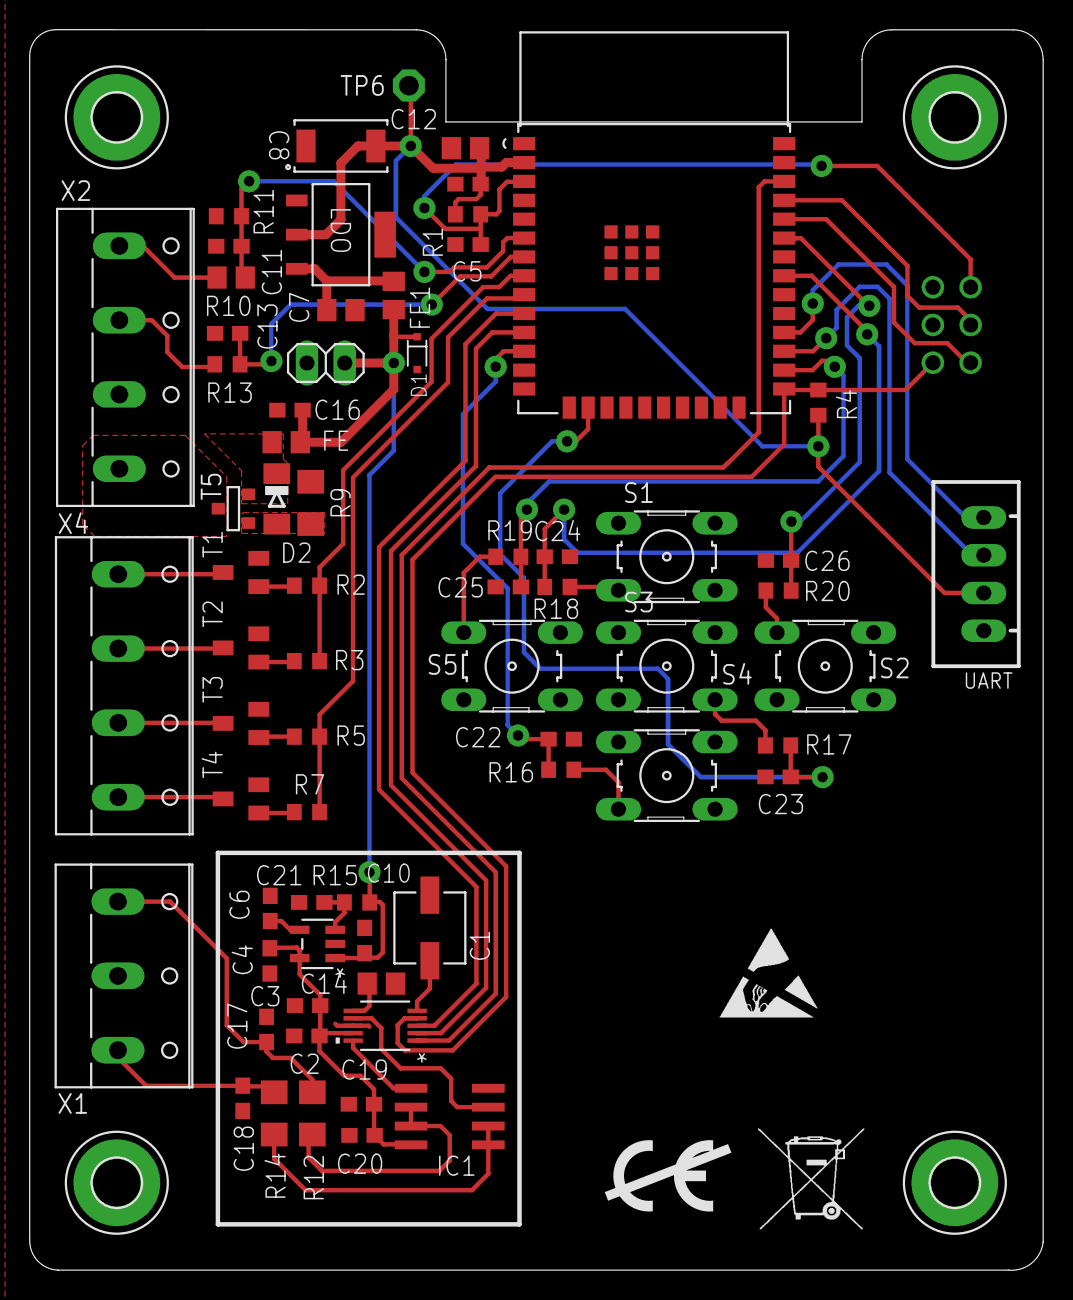
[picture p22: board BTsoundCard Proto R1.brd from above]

Board: 2 copper layers, 68.2 x 83.5 mm, 73 parts (1 on the bottom side), 51 nets.

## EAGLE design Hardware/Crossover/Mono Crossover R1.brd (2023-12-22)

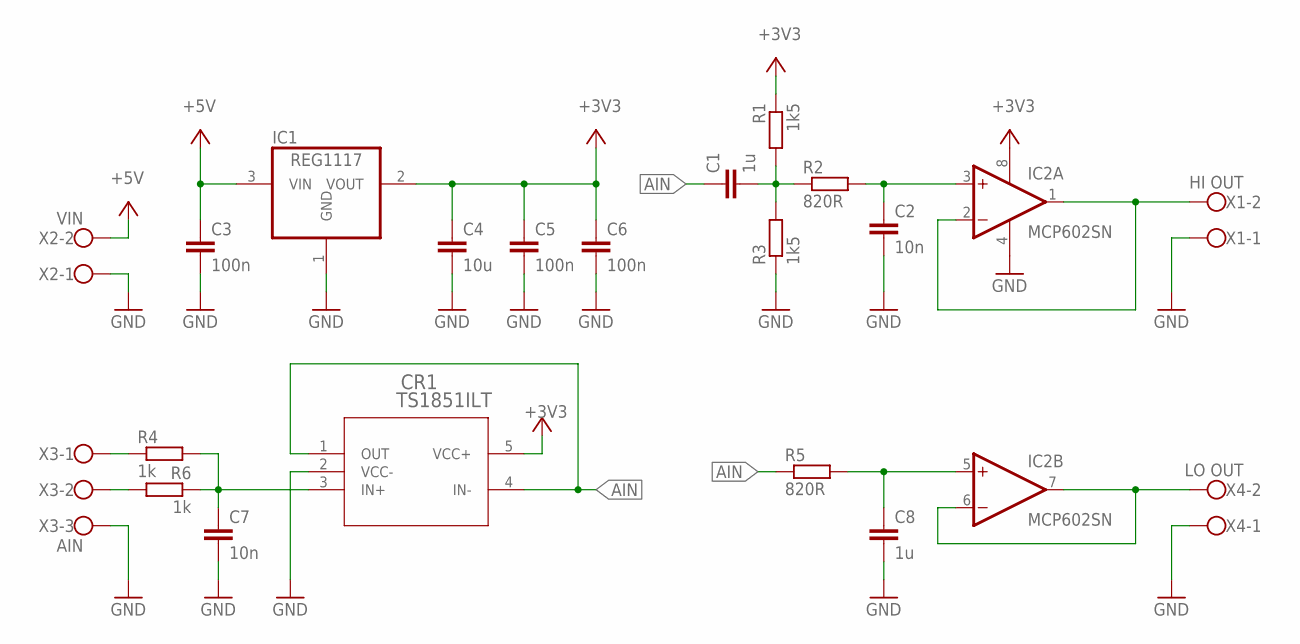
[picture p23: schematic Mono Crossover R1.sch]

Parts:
C1, C8: 1u; C0805
C2, C7: 10n; C0603
C3, C5, C6: 100n; C0603
C4: 10u; C1206
CR1: TS1851ILT; SOT23-5L_STM
IC1: REG1117; SOT223
IC2: MCP602SN; SO08
R1, R3: 1k5; R0805
R2, R5: 820R; R1206
R4, R6: 1k; R0603
X1: HI OUT; W237-102
X2: VIN; W237-102
X3: AIN; W237-103
X4: LO OUT; W237-102

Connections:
+3V3: C4.1, C5.1, C6.1, CR1.5 (VCC+), IC1.2 (VOUT), IC2.8 (V+), R1.1
+5V: C3.1, IC1.3 (VIN), X2.2
AIN: C1.1, CR1.1 (OUT), CR1.4 (IN-), R5.1
GND: C2.2, C3.2, C4.2, C5.2, C6.2, C7.2, C8.2, CR1.2 (VCC-), IC1.1 (GND), IC2.4 (V-), R3.1, X1.1, X2.1, X3.3, X4.1
HI_OUT: IC2.1 (OUT), IC2.2 (-IN), X1.2
LO_OUT: IC2.6 (-IN), IC2.7 (OUT), X4.2
unnamed: R4.1, X3.1
unnamed: R6.2, X3.2
unnamed: C2.1, IC2.3 (+IN), R2.2
unnamed: C1.2, R1.2, R2.1, R3.2
unnamed: C8.1, IC2.5 (+IN), R5.2
unnamed: C7.1, CR1.3 (IN+), R4.2, R6.1

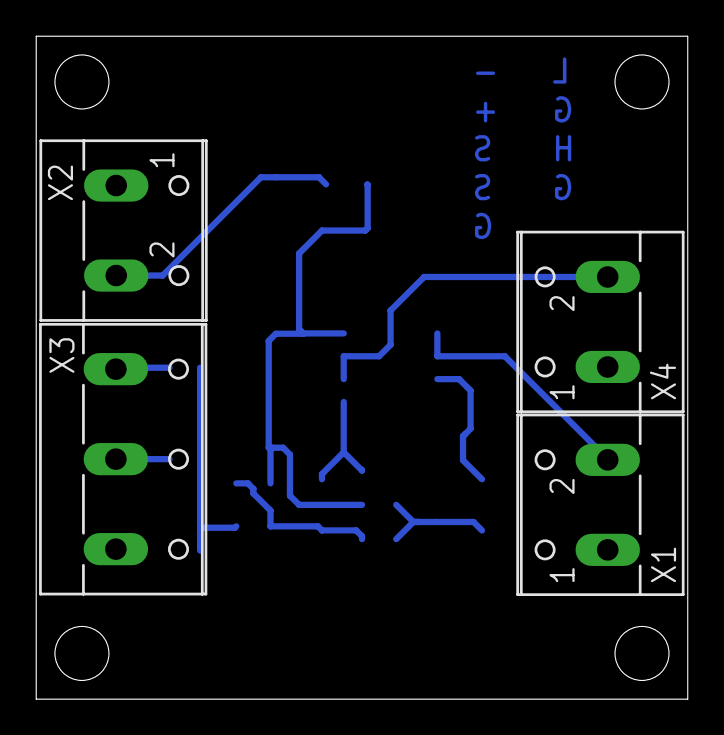
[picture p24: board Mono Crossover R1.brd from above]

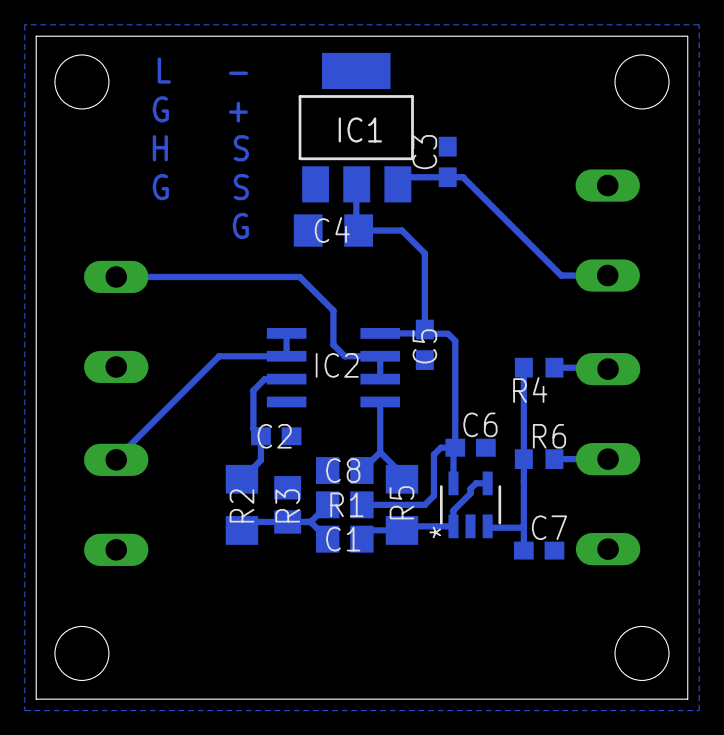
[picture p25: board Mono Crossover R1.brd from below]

Board: 2 copper layers, 36.2 x 36.8 mm, 21 parts (17 on the bottom side), 12 nets.

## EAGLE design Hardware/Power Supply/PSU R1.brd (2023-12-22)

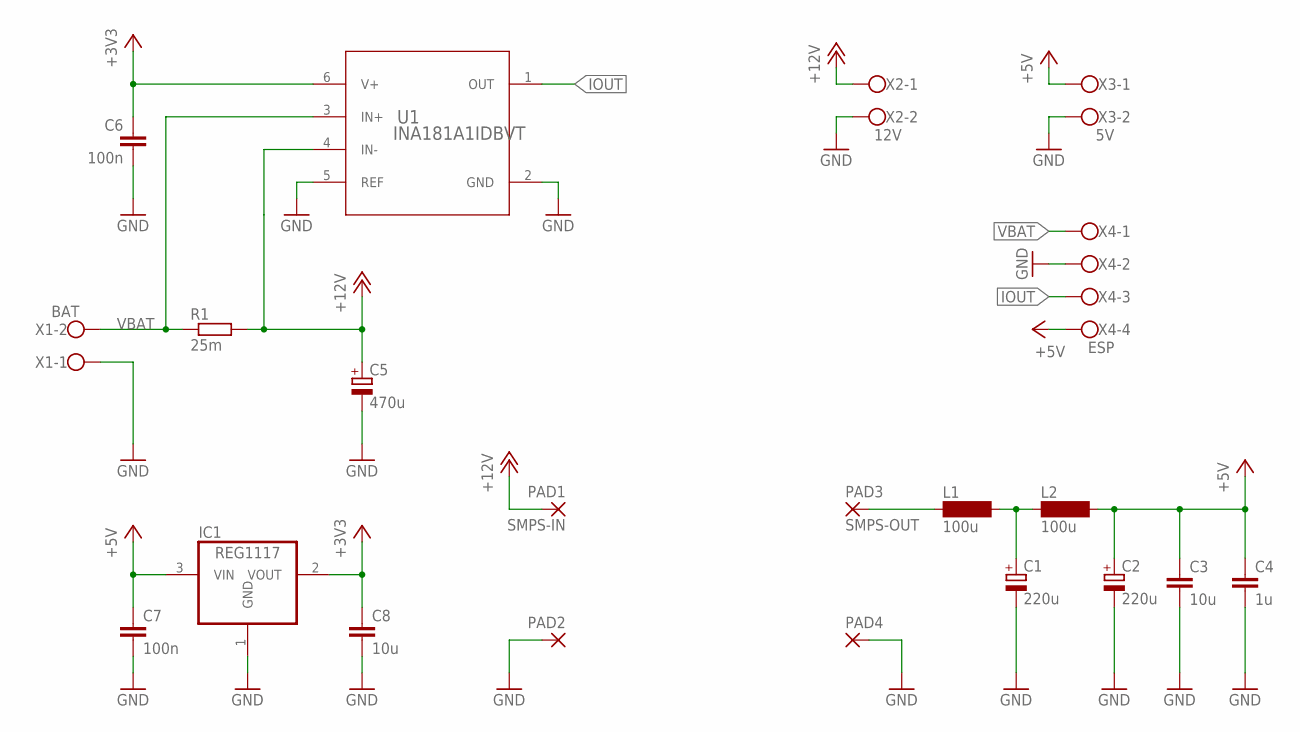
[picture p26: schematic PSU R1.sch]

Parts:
C1, C2: 220u; E2,5-6
C3, C8: 10u; C1206
C4: 1u; C0805
C5: 470u; E5-10,5
C6, C7: 100n; C0603
IC1: REG1117; SOT223
L1, L2: 100u; SD8
PAD1: SMPS-IN; 1,6/0,9
PAD2, PAD4: 1,6/0,9
PAD3: SMPS-OUT; 1,6/0,9
R1: 25m; R2512
U1: INA181A1IDBVT; DBV0006A_N
X1: BAT; W237-102
X2: 12V; W237-102
X3: 5V; W237-102
X4: ESP; W237-4

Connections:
+3V3: C6.1, C8.1, IC1.2 (VOUT), U1.6 (V+)
+5V: C2.+, C3.1, C4.1, C7.1, IC1.3 (VIN), L2.2, X3.1, X4.4
+12V: C5.+, PAD1.1, R1.2, U1.4 (IN-), X2.1
GND: C1.-, C2.-, C3.2, C4.2, C5.-, C6.2, C7.2, C8.2, IC1.1 (GND), PAD2.1, PAD4.1, U1.2 (GND), U1.5 (REF), X1.1, X2.2, X3.2, X4.2
IOUT: U1.1 (OUT), X4.3
unnamed: L1.1, PAD3.1
unnamed: C1.+, L1.2, L2.1
VBAT: R1.1, U1.3 (IN+), X1.2, X4.1



Board: 2 copper layers, 85.1 x 36.2 mm, 21 parts (8 on the bottom side), 8 nets.

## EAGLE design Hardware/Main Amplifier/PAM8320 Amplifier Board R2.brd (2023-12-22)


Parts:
C1, C2, C6, C7, C11, C12, C13: 1u; C0805
C3, C4, C10: 10u; C1206
C5: 470n; C1206
C8, C9: 220u; UD-10X10_NICHICON
L1, L2: 47u; DR127
Q1: BC857B; SOT23-BEC
R1: 100R; R0603
R2: 10k; RJ9W
R4, R6, R7: 10k; R0603
R5: 1k; R0603
U1: PAM8320RDR; SO-16EP_3P9X9P9_DIO
X1: OUT; W237-102
X2: VIN; W237-102
X3: AIN; W237-102
X4: CTRL; W237-103

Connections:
AIN: R2.E, X3.2
AVCC: C10.1, C11.1, R1.2, U1.13 (AVCC)
BSN: C2.1, U1.14 (BSN)
BSP: C1.1, U1.11 (BSP)
GND: C3.2, C4.2, C6.2, C7.2, C8.-, C9.-, C10.2, C11.2, C12.2, C13.2, R5.1, R7.2, U1.5 (AGND_2), U1.6 (AGND), U1.9 (PGNDP), U1.16 (PGNDN), U1.17 (EPAD), X2.1, X3.1, X4.1
MUTE: R4.1, U1.12 (MUTE), X4.2
unnamed: Q1.B, R6.2
unnamed: C12.1, U1.7 (VCLAMP)
unnamed: C13.1, U1.4 (VCM)
unnamed: C5.1, R2.A, R2.S, R5.2
unnamed: C5.2, U1.3 (IN)
unnamed: R6.1, X4.3
NSDN: Q1.C, R7.1, U1.2 (SDN)
OUTN: C3.1, L2.1, X1.2
OUTP: C4.1, L1.2, X1.1
OUT_N: C2.2, L2.2, U1.15 (OUTN)
OUT_P: C1.2, L1.1, U1.10 (OUTP)
V+: C6.1, C7.1, C8.+, C9.+, Q1.E, R1.1, R4.2, U1.1 (PVCCN), U1.8 (PVCCP), X2.2



Board: 2 copper layers, 64.1 x 47.0 mm, 27 parts (22 on the bottom side), 18 nets.

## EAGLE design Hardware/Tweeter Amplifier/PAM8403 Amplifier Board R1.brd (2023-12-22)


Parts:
C1, C2: 330u; E3,5-8
C3, C6: 470n; C1206
C4, C5: 1u; C1206
L1: 22u; R0805
R2: 100R; R0603
U1: PAM8403DR; SOIC_8403DR_DIO
X1: VIN; W237-102
X2: AIN; W237-103
X3: CTRL; W237-103
X4: OUT; W237-4

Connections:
AGND: C4.2, C5.2, L1.1, U1.11 (GND), X2.2, X3.3
AVCC: C4.1, R2.2, U1.6 (VDD)
GND: C1.-, C2.-, L1.2, U1.2 (PGND_2), U1.15 (PGND), X1.1
INL: C6.1, X2.3
INR: C3.1, X2.1
L+: U1.1 (+OUT_L), X4.1
L-: U1.3 (-OUT_L), X4.2
MUTE: U1.5 (MUTE), X3.2
unnamed: C3.2, U1.10 (INR)
unnamed: C6.2, U1.7 (INL)
unnamed: C5.1, U1.8 (VREF)
R+: U1.16 (+OUT_R), X4.4
R-: U1.14 (-OUT_R), X4.3
SDN: U1.12 (SHND), X3.1
V+: C1.+, C2.+, R2.1, U1.4 (PVDD_2), U1.13 (PVDD), X1.2

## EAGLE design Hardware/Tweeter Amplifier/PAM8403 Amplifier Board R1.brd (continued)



Board: 2 copper layers, 45.1 x 40.6 mm, 13 parts (7 on the bottom side), 15 nets.

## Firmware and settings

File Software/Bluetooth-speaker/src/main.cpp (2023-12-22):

#include <Arduino.h>
#include "BluetoothA2DPSink.h"

#define AUDIO_PLAYING 2

#define AMPLIFIER_ON 1
#define AMPLIFIER_OFF 0
#define MUTE_ON 0
#define MUTE_OFF 1

//calculated according to hardware specs
#define PSU_OVERCURRENT_PROTECTION_THR 1600 // 1600 adc units is 3A from battery
#define BATTERY_UNDERVOLTAGE_THR 2200 // 2200 adc units is 7.7V on battery

#define SAMPLING_THR 100

BluetoothA2DPSink a2dp_sink;

const int volumeUpPin = 4; //S5 on board
const int volumeDownPin = 21; //S2 on board
const int previousSongPin = 27; //S3 on board
const int nextSongPin = 19; //S1 on board
const int playOrPausePin = 13; //S4 on board

const int amplifierShutdownPin = 33;
const int amplifierMutePin = 32;

const int ADCPsuCurrentPin = 35;
const int ADCBatteryPin = 34;

uint8_t errorCounter = 0;

void setup() {

    delay(2000); //wait voltages to stabilize
    Serial.begin(9600); //debug

    pinMode(volumeUpPin, INPUT_PULLUP);
    pinMode(volumeDownPin, INPUT_PULLUP);
    pinMode(previousSongPin, INPUT_PULLUP);
    pinMode(nextSongPin, INPUT_PULLUP);
    pinMode(playOrPausePin, INPUT_PULLUP);

    pinMode(amplifierShutdownPin, OUTPUT);
    pinMode(amplifierMutePin, OUTPUT);

    a2dp_sink.start("Turboencabulator");

    digitalWrite(amplifierShutdownPin, AMPLIFIER_ON);
    digitalWrite(amplifierMutePin, MUTE_OFF);
}

void loop() {

    delay(10);

    if(analogRead(ADCBatteryPin) < BATTERY_UNDERVOLTAGE_THR || analogRead(ADCPsuCurrentPin) > PSU_OVERCURRENT_PROTECTION_THR) {
        errorCounter++;
        if(errorCounter > SAMPLING_THR) {
            Serial.println("Error state");
            digitalWrite(amplifierShutdownPin, AMPLIFIER_OFF);
            digitalWrite(amplifierMutePin, MUTE_ON);
            while(1) {
                sleep(1000);
            }    
        }
    }

    while(!a2dp_sink.is_connected()) {
        return;
    }

    if(!digitalRead(volumeDownPin)) {
          uint8_t volume = a2dp_sink.get_volume();
          volume--;
          a2dp_sink.set_volume(volume);
    }

    if(!digitalRead(volumeUpPin)) {
          uint8_t volume = a2dp_sink.get_volume();
          volume++;
          a2dp_sink.set_volume(volume);
    }

    if(!digitalRead(previousSongPin)) {
          a2dp_sink.previous();
    }

    if(!digitalRead(nextSongPin)) {
          a2dp_sink.next();
    }
    
    if(!digitalRead(playOrPausePin)) {
        if(AUDIO_PLAYING == a2dp_sink.get_audio_state()) {
            a2dp_sink.pause();
            return;
        }
        a2dp_sink.play();
    }
}

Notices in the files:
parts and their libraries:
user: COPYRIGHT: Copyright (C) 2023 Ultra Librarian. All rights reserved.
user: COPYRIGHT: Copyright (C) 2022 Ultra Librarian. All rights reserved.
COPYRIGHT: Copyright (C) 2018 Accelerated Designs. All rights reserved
